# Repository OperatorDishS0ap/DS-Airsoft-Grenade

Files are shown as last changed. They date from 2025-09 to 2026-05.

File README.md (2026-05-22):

# DS-Airsoft-Grenade
## Current Release: [V5](/V5)
This project is a reusable, timed or impact-activated airsoft simulation grenade designed to operate with .209 primers, 8-shot ring caps, or adult/thunder/super snaps. The device is engineered with a strong emphasis on reliability, repeatability, and user safety. It is a zero-fragmentation system intended solely to produce an audible report, with no shrapnel or expelled components during operation. All exhaust gases and particulate byproducts are redirected and dispersed internally before exiting the device, significantly reducing localized pressure and minimizing external explosive forces.  
The design prioritizes consistent performance across a wide range of 3D printers and environmental conditions. Each component is optimized for printability, structural strength, and impact resistance while maintaining a compact form factor and minimal overall mass. A modular architecture allows both timed and impact fuse mechanisms to be easily interchanged between grenade bodies and compatible ammunition types, enabling flexibility in configuration, maintenance, and future expansion. This modularity, combined with durable construction, ensures the system remains adaptable, cost-effective, and dependable for repeated use in simulation environments.  

There may be inconsistencies with posted youtube videos and the current version or function. Please review the current [release](/V5)

Demo

[Ammo Comparison](https://youtube.com/shorts/NLlh_alYXCA?si=77kgigL3ZdaDLs44)

These are strictly for training and airsoft purposes. I do not assume any responsibility for your misuse or injury.  

# Changelog

All notable changes to this project will be documented below

## [5.0] - 2026-04-19  

###
- Created GitHub repository that will operate as the primary project resource
- All components have been redesigned for printability, reliability, and ease of use
- Added Multi-Shot Primer Body
- Changed from M5 SHCS Bolt to M4 FHCS and altered the guide to be bolted rather than press fit or glued
- Added aditional spring clearance for the use of uxcell springs
- Added aditional spring for increased spring strength
- New PCB design that implements a limit switch, battery protection, and LED indicator
- Time fuse is now activated with a pin
- Text size increased for multi-color printing
- Added constant force primer hole for better primer retention

## [4.2] – 2025-05-28

### Added
- New **timer design utilizing a custom PCB**
  - Supports **2S Li-Po** with a standard charger
  - No wires, hot glue, or crimping required
  - See the V4 release video or assembly video for details
- Motor removal access hole beneath the motor shaft
  - Allows easy motor removal using a metal rod
- Tool to assist with press-fitting the bolt guide
- **55-round snap body**
- V4 release video
- Updated assembly video

### Changed
- Enlarged **main bolt hole** and **bolt guide hole**
- External fuse body geometry updated for improved printability and durability
- Increased bolt guide height to further prevent slipping
- Completely redesigned spoon geometry
  - Printable in **TPU or PLA** using the same file
  - TPU remains recommended
  - Added groove to reduce sensitivity
- Inverted 8-cap orientation for easier use
- Increased snap hole sizes for easier removal
- Updated instructions and BOM
- Updated spring specification to **45 mm length or 8 coils**
  - See instructions for additional details

---

## [4.1] – 2025-02-19

### Fixed
- Corrected spelling on **8-cap** and **snap bodies**

### Added
- Long primer bodies (**DS38PL – PFL**)

---

## [4.0] – 2025-02-18

### Fixed
- Corrected BOM to list the proper **M2.5 × 3 mm set screw** for the timed fuse  
  - Previously listed **M2 set screw** may still work but can require adhesive or fail prematurely

### Added
- **DS40F no-text body**
- Initial **V4 release**

### Improvements
- Added support for **8-shot caps**, **adult snaps**, **super snaps**, and **thunder snaps**
- Reduced overall device size
- Added built-in guide on primer bodies for improved main bolt alignment
- Updated fuse dimensions for **40 mm half-thread bolt**
  - Smoother action
  - Smaller profile
- Converted bolt guide to a **press-fit design**
- Fuse now recesses into the body for improved strength
- Updated spoon dimensions
- Improved primer hole sizing



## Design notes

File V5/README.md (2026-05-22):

# PLEASE READ THE INSTRUCTIONS BELOW THOROUGHLY AND WATCH THE VIDEO LINKED BELOW BEFORE ASKING QUESTIONS

Assembly video can be found here: [Assembly Video](https://youtu.be/WyIGIuh09i8)

A video showing how to order the PCB can be found here: 

For further questions and resources join the [Discord](https://discord.gg/FcNPHcn7kz) server 

| Navigation |
| ------------------------ |
| [Printed Parts](#printed-parts) |
| [Impact Fuse BOM](#impact-fuse-bill-of-materials) |
| [Timed Fuse BOM](#impact-fuse-bill-of-materials) |
| [Impact Fuse Assembly](#impact-fuse-assembly) |
| [Timed Fuse Assembly](#timed-fuse-assembly) |
| [Body Assembly and Function](#body-assembly-and-function) |
| [Additional Material Info](#additional-material-info) |

# Printed Parts:
The tables below outline the printed parts necissary for each core component. You will need a fuse type and a body type. All fuses and bodies are interchangable. Links are to the corresponding file folders. **Materials are ordered from most to least recomended** If a material is not listed do not use it.
## Printed Parts for Impact Fuse:
| Part | QTY | Slicer Settings | Material | Support |
| --- | --- | --- | --- | --- |
| [Fuse](STL/ImpactFuse/FuseV5.STL) | 1 | ≤ 0.20mm layer height <br> Wall, top, and bottom thickness: ≥ 2 mm (5 walls for 0.4mm nozzle) <br> ≥ 35% Gyroid or Cubic Infill | TPU 72D <br> Nylon <br> PLA+ | No |
| [Bolt Guide](STL/ImpactFuse/BoltGuideV5.STL) | 1 | ≤ 0.16mm layer height <br> Wall, top, and bottom thickness: ≥ 2 mm (5 walls for 0.4mm nozzle) <br> 100% Infill | TPU 72D <br> Nylon | Yes |
| [Spring Plate](STL/ImpactFuse/SpringPlateV5.STL) | 1 | ≤ 0.16mm layer height <br> Wall, top, and bottom thickness: ≥ 2 mm (5 walls for 0.4mm nozzle) <br> 100% Infill | TPU 72D <br> Nylon | Yes |
| [Spoon](STL/ImpactFuse/Spoon) | 1 | ≤ 0.20mm layer height <br> Wall, top, and bottom thickness: ≥ 2 mm (5 walls for 0.4mm nozzle) <br> 100% Infill | TPU72D <br> TPU 95A | No |

## Printed Parts for Timed Fuse:
| Part | QTY | Slicer Settings | Material | Support |
| --- | --- | --- | --- | --- |
| [Fuse](STL/TimedFuse/PCBPinFuseV5.STL) | 1 | ≤ 0.20mm layer height <br> Wall, top, and bottom thickness: ≥ 2 mm (5 walls for 0.4mm nozzle) <br> ≥ 35% Gyroid or Cubic Infill | TPU 72D <br> Nylon <br> PLA+ | No |
| [Bolt Guide](STL/ImpactFuse/BoltGuideV5.STL) | 1 | ≤ 0.16mm layer height <br> Wall, top, and bottom thickness: ≥ 2 mm (5 walls for 0.4mm nozzle) <br> 100% Infill | TPU 72D <br> Nylon | Yes |
| [Spring Plate](STL/ImpactFuse/SpringPlateV5.STL) | 1 | ≤ 0.16mm layer height <br> Wall, top, and bottom thickness: ≥ 2 mm (5 walls for 0.4mm nozzle) <br> 100% Infill | TPU 72D <br> Nylon | Yes |
| [Cam](STL/TimedFuse/CamV5.STL) | 1 | ≤ 0.16mm layer height <br> Wall, top, and bottom thickness: ≥ 2 mm (5 walls for 0.4mm nozzle) <br> 100% Infill | ABS (CF/GF) <br> CF/GF Nylon <br> PLA+ | No |
| [Cap](STL/TimedFuse/CapV5.STL) | 1 | ≤ 0.20mm layer height <br> Wall, top, and bottom thickness: ≥ 2 mm (5 walls for 0.4mm nozzle) <br> ≥ 35% Gyroid or Cubic Infill | TPU 72D <br> Nylon <br> PLA+ | No |
| [Switch Lever](STL/TimedFuse/SwitchLeverV5.STL) | 1 | ≤ 0.20mm layer height <br> Wall, top, and bottom thickness: ≥ 2 mm (5 walls for 0.4mm nozzle) <br> ≥ 35% Gyroid or Cubic Infill | TPU 72D <br> Nylon <br> PLA+ | No |

## Printed Parts for Primer Body:
| Part | QTY | Slicer Settings | Material | Support |
| --- | --- | --- | --- | --- |
| [Body](STL/PrimerBody) | 1 | ≤ 0.20mm layer height <br> Wall, top, and bottom thickness: ≥ 2 mm (5 walls for 0.4mm nozzle) <br> ≥ 35% Gyroid or Cubic Infill | TPU 72D <br> Nylon | No |

## Printed Parts for Multi-Primer Body:
| Part | QTY | Slicer Settings | Material | Support |
| --- | --- | --- | --- | --- |
| [Body](STL/PrimerBody) | 1 | ≤ 0.20mm layer height <br> Wall, top, and bottom thickness: ≥ 2 mm (5 walls for 0.4mm nozzle) <br> ≥ 35% Gyroid or Cubic Infill | TPU 72D <br> Nylon | Yes |
| [Holder](STL/PrimerBody/Holder_X4.STL) | 1 | ≤ 0.16mm layer height <br> Wall, top, and bottom thickness: ≥ 2 mm (5 walls for 0.4mm nozzle) <br> ≥ 100% Infill | Nylon <br> PLA+ | No |

## Printed Parts for Snap Body
| Part | QTY | Slicer Settings | Material | Support |
| --- | --- | --- | --- | --- |
| [Body](STL/SnapBody) | 1 | ≤ 0.20mm layer height <br> Wall, top, and bottom thickness: ≥ 2 mm (5 walls for 0.4mm nozzle) <br> ≥ 35% Gyroid or Cubic Infill | TPU 72D <br> Nylon | Only for 55 Body |
| [Base](STL/SnapBody) | 1 | ≤ 0.20mm layer height <br> Wall, top, and bottom thickness: ≥ 2 mm (5 walls for 0.4mm nozzle) <br> ≥ 35% Gyroid or Cubic Infill | TPU 72D <br> TPU 95A <br> Nylon | No |

## Printed Parts for 8-Cap Body
| Part | QTY | Slicer Settings | Material | Support |
| --- | --- | --- | --- | --- |
| [Body](STL/CapBody) | 1 | ≤ 0.20mm layer height <br> Wall, top, and bottom thickness: ≥ 2 mm (5 walls for 0.4mm nozzle) <br> ≥ 35% Gyroid or Cubic Infill | TPU 72D <br> Nylon | No |
| [Retainer](STL/CapBody/CapRetainerV5.STL) | 1 | ≤ 0.16mm layer height <br> Wall, top, and bottom thickness: ≥ 2 mm (5 walls for 0.4mm nozzle) <br> ≥ 100% Infill | Nylon <br> PLA+ | No |

# Impact Fuse Bill of Materials:
### Please **VERIFY** that you are ordering the same component listed below. The links do not direct you to the exact size/specification you will need.

| Item | Quantity | Amazon | AliExpress | Notes |
| ---- | --- | --- | --- | --- |
| M4x45mm FHCS | 1 | [link](https://www.amazon.com/dp/B0D42CX288) | [link](https://www.aliexpress.us/item/3256807652024221.html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) | Main Bolt |
| M3x30mm Countersunk Self-Tapping Screw | 1 | [link](https://www.amazon.com/dp/B0D3ZW49WJ) | [link](https://www.aliexpress.us/item/3256807541973336.html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) | Spoon Bolt |
| 12mm OD x 40mm 1.2mm Diameter Spring | 1 | [link](https://www.amazon.com/dp/B076M2CBSX?ref_=ppx_hzsearch_conn_dt_b_fed_asin_title_2) | [link](https://www.aliexpress.us/item/2255800219014836.html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) | Primary Spring<br>See Comments Below |
| 8mm OD x 30mm 1mm Diameter Spring | 1 | [link]() | [link](https://www.aliexpress.us/item/3256805216136796.html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) | Secondary Spring<br>See Commenst Below |
| M4 Nut | 2 | [link](https://www.amazon.com/ZQZ-M4-0-7mm-Stainless-Hardware-Standard/dp/B0CQJJV8Q8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) | [link](https://www.aliexpress.us/item/2255800416538696.html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,scm-url:1007.40050.354490.0,pvid:712b6b0e-e0c3-48aa-a997-7cb9d9db5a1e,tpp_buckets:668%232846%238115%232000&pdp_ext_f=%7B%22order%22%3A%2211641%22%2C%22spu_best_type%22%3A%22price%22%2C%22eval%22%3A%221%22%2C%22sceneId%22%3A%2230050%22%2C%22fromPage%22%3A%22recommend%22%7D&pdp_npi=6%40dis%21USD%211.03%211.03%21%21%211.03%211.03%21%40210319b017731671023242410e8d3a%2110000003767007634%21rec%21US%212397384802%21XZ%211%210%21n_tag%3A-29919%3Bd%3A76bd9575%3Bm03_new_user%3A-29895&utparam-url=scene%3ApcDetailTopMoreOtherSeller%7Cquery_from%3A%7Cx_object_id%3A4000602853448%7C_p_origin_prod%3A) | For the Bolt and Spring Guide |
| M3x20mm Countersunk Self-Tapping Screw | 4 | [link](https://www.amazon.com/dp/B0D3ZW49WJ) | [link](https://www.aliexpress.us/item/3256807541973336.html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) | Fuse Reinforcement |
| 25mm/1" Keyring | 1 | [link](https://www.amazon.com/PAXCOO-Keyrings-Split-Keychain-Crafts/dp/B076Q9SSSQ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) | [link](https://www.aliexpress.us/item/3256804511691476.html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) | |
| M2.5x35mm Cotter Pin | 1 | [link]() | [link](https://www.aliexpress.us/item/3256804075588876.html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) | |
| M3 Brass Heat Insert 5mmODx4mmL | 1 | [link](https://www.amazon.com/dp/B0F43D2TTH) | [link](https://www.aliexpress.us/item/3256803396040989.html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) | Not necissary, only for increased durability |

Primary springs ordered from other locations may have differing coil counts. The recommended coil count is ~10-11, however, some experimentation may be needed. Both springs linked will work without modification. In the case the spring is unable to compress enough, either cut and stretch the spring, or purchase a shorter length and stretch to fit. If you find your springs too weak, increase in length. I recommend purchasing a few varying lengths or further discuss with others on the discord to find a good spring.  

The secondary spring is to add spring strength for the primer and 8-cap and is not necessary for the snap rounds.  

Springs will lose their strength over time and will need to be replaced. Avoid leaving springs compressed over long periods of time, as this will rapidly decrease their lifespan.

# Timed Fuse Bill of Materials:
### Please **VERIFY** that you are ordering the same component listed below. The links do not direct you to the exact size/specification you will need.

| Item | Quantity | Amazon | AliExpress | Notes |
| ---- | --- | --- | --- | --- |
| M4x45mm FHCS | 1 | [link](https://www.amazon.com/dp/B0D42CX288) | [link](https://www.aliexpress.us/item/3256807652024221.html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) | Main Bolt |
| 12mm OD x 40mm 1.2mm Diameter Spring | 1 | [link](https://www.amazon.com/dp/B076M2CBSX?ref_=ppx_hzsearch_conn_dt_b_fed_asin_title_2) | [link](https://www.aliexpress.us/item/2255800219014836.html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) | Primary Spring<br>See Comments Below |
| 8mm OD x 30mm 1mm Diameter Spring | 1 | [link]() | [link](https://www.aliexpress.us/item/3256805216136796.html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) | Secondary Spring<br>See Commenst Below |
| M4 Nut | 2 | [link](https://www.amazon.com/ZQZ-M4-0-7mm-Stainless-Hardware-Standard/dp/B0CQJJV8Q8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) | [link](https://www.aliexpress.us/item/2255800416538696.html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,scm-url:1007.40050.354490.0,pvid:712b6b0e-e0c3-48aa-a997-7cb9d9db5a1e,tpp_buckets:668%232846%238115%232000&pdp_ext_f=%7B%22order%22%3A%2211641%22%2C%22spu_best_type%22%3A%22price%22%2C%22eval%22%3A%221%22%2C%22sceneId%22%3A%2230050%22%2C%22fromPage%22%3A%22recommend%22%7D&pdp_npi=6%40dis%21USD%211.03%211.03%21%21%211.03%211.03%21%40210319b017731671023242410e8d3a%2110000003767007634%21rec%21US%212397384802%21XZ%211%210%21n_tag%3A-29919%3Bd%3A76bd9575%3Bm03_new_user%3A-29895&utparam-url=scene%3ApcDetailTopMoreOtherSeller%7Cquery_from%3A%7Cx_object_id%3A4000602853448%7C_p_origin_prod%3A) | For the Bolt and Spring Guide |
| M2.5x20mm Countersunk Self-Tapping Screw | 4 | [link]() | [link](https://www.aliexpress.us/item/3256807541973336.html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) | Fuse Cap Fastners and Reinforcement |
| 25mm/1" Keyring | 1 | [link](https://www.amazon.com/PAXCOO-Keyrings-Split-Keychain-Crafts/dp/B076Q9SSSQ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) | [link](https://www.aliexpress.us/item/3256804511691476.html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) | |
| M2.5x35mm Cotter Pin | 1 | [link]() | [link](https://www.aliexpress.us/item/3256804075588876.html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) | |
| Motor 12V 30RPM | 1 | [link](https://www.amazon.com/uxcell-Micro-Motor-10RPM-Reducer/dp/B01ES98QSG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)<br>[link](https://www.amazon.com/DC-Motor-1000-Miniature-3V-12V/dp/B08K9B1W5M/ref=sr_1_2?s=industrial&sr=1-2) | [link](https://www.alibaba.com/product-detail/Quiet-12mm-Ga12-n20-N10-N20_1600287077566.html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) | **DO NOT ORDER THE WRONG MOTOR**<br>See Comments Below To ensure you order the correct motor |
| 100mAh 3.7V Li-Po w/ JST PH2.0mm Connector | 2 | [link]() | [link]() | See the Image Below for Battery Space Measurements |
| Male JST PH2.00mm 3P Connector | 1 | [link](https://www.amazon.com/CQRobot-Pieces-Connector-Housing-Adapter/dp/B09YY18S91/ref=sr_1_6?sr=8-6) | [link](https://www.aliexpress.us/item/3256804853397341.html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) | Charger Cable |
| Male JST XH2.54mm 3P Connector | 1 | [link](https://www.amazon.com/Antrader-Silicone-Battery-Extension-Connector/dp/B07TTR598D/ref=sr_1_9?sr=8-9) | [link](https://www.aliexpress.us/item/3256806041022852.html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) | This is for charging the 2S Li-Po in the fuse. I recommend purchasing a 2S Li-Po balance lead and crimping the JST PH2.0mm connector to the end. Otherwise, you can crimp the connectors on both ends. |
| M2.5x3mm Set Screw | 1 | [link](https://www.amazon.com/100pcs-Stainless-Socket-Screws-Metric/dp/B01MTM26H0/ref=sr_1_9?sr=8-9) | [link](https://www.aliexpress.us/item/2255800895118752.html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) | Timer Cam |
| Limit Switch SPDT | 1 | [link]() | [link](https://www.aliexpress.us/item/3256805410237576.html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) | Ensure you get a side mount switch <br> The metal switch lever will be removed |
| PCB | 1 | | | PCB [Files](PCB) are above<br>A [video]() showing how to order the board is linked above |
| Female JST PH2.0mm 2P Vertical Header | 2 | [link](https://www.amazon.com/CQRobot-Pieces-Connector-Housing-Adapter/dp/B09DP9FZTX/ref=sr_1_6?s=industrial&sr=1-6) | [link](https://www.aliexpress.us/item/3256806894018733.html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) | Battery PCB Header |
| Female JST PH2.0mm 3P Horizontal Header | 1 | [link](https://www.amazon.com/CQRobot-Pieces-Connector-Housing-Adapter/dp/B09YY18S91/ref=sr_1_6?sr=8-6) | [link](https://www.aliexpress.us/item/3256804853397341.html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) | Battery PCB Charge Port Header |

**DO NOT ORDER THE WRONG MOTOR.** It is Very important that you purchase a 12V-30rpm/6V-15rpm motor. The gearbox is ~12.5mm vs the standard 9mm. The gearbox has ~1:1000 ratio. Please be careful to order the correct motor, others will not work. I recommend ordering from the Alibaba link, please specify the **“KGM12-N20-C. 12V 1/1000 reduction ratio”** when ordering.  

Primary springs ordered from other locations may have differing coil counts. The recommended coil count is ~10-11, however, some experimentation may be needed. Both springs linked will work without modification. In the case the spring is unable to compress enough, either cut and stretch the spring, or purchase a shorter length and stretch to fit. If you find your springs too weak, increase in length. I recommend purchasing a few varying lengths or further discuss with others on the discord to find a good spring.  

The secondary spring is to add spring strength for the primer and 8-cap and is not necessary for the snap rounds.  

Springs will lose their strength over time and will need to be replaced. Avoid leaving springs compressed over long periods of time, as this will rapidly decrease their lifespan.

Battery compartment dimensions are below in millimeters. You will have to explore options for batteries since listings change per country. Verify that it has a JST PH 2.0mm connector or crimp your own.

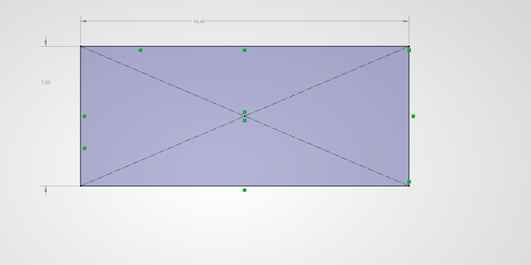
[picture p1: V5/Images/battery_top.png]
Top Battery Space

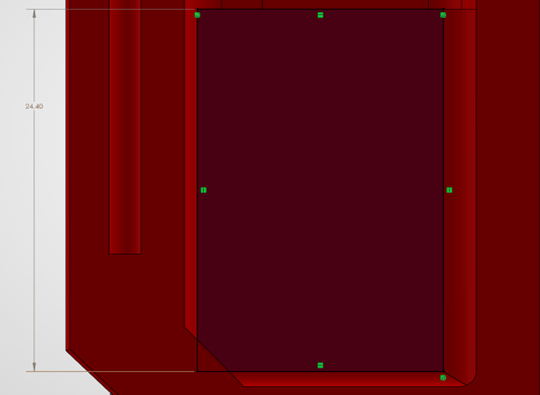
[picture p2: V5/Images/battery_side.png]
Side Battery Space


# Multi-Primer Bill of Materials:
### Please **VERIFY** that you are ordering the same component listed below. The links do not direct you to the exact size/specification you will need.

| Item | Quantity | Amazon | AliExpress |
| ---- | --- | --- | --- |
| 3mm OD x 20mm 0.4mm Spring | 1 | [link](https://www.amazon.com/uxcell-Compression-Spring-Stainless-Length/dp/B0C33CBS5Y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) | [link](https://www.aliexpress.us/item/3256805216186612.html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) |
| 3.175mm / 1/8" Ball Bearing | 1 | [link](https://www.amazon.com/uxcell-8-inch-Bearing-Stainless-Precision/dp/B07YFXDZQS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) | [link](https://www.aliexpress.us/item/3256805018276561.html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) |
| M3x20mm BHCS | 1 | [link](https://www.amazon.com/iexcell-Thread-Socket-Button-Screws/dp/B0CP49NWYB/ref=sr_1_3?sr=8-3) | [link](https://www.aliexpress.us/item/2251832780910689.html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,scm-url:1007.40050.354490.0,pvid:030ae71f-b872-4ad4-aca8-7f85ee968ba4,tpp_buckets:668%232846%238115%232000&pdp_ext_f=%7B%22order%22%3A%2214068%22%2C%22eval%22%3A%221%22%2C%22sceneId%22%3A%2230050%22%2C%22fromPage%22%3A%22recommend%22%7D&pdp_npi=6%40dis%21USD%211.11%211.11%21%21%211.11%211.11%21%4021033d1217731699782175040ecb48%2112000015921238834%21rec%21US%212397384802%21X%211%210%21n_tag%3A-29919%3Bd%3A76bd9575%3Bm03_new_user%3A-29895&utparam-url=scene%3ApcDetailTopMoreOtherSeller%7Cquery_from%3A%7Cx_object_id%3A32967225441%7C_p_origin_prod%3A) |
| M4x5mm Set Screw | 1 | [link](https://www.amazon.com/ZDingTech-110pcs-Screws-Stainless-Hexagon/dp/B0CF299SDT/ref=sr_1_3?sr=8-3) | [link](https://www.aliexpress.us/item/2255800895118752.html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) |

# Impact Fuse Assembly:
#### It is recommended to watch the assembly video as well

1. To start, for the primer version only, grind the end of the fuse screw (m4x45mm) to a bevel as shown in the image below. Do not sharpen the tip this will puncture the primer. A point around 3mm in diameter is ideal.  
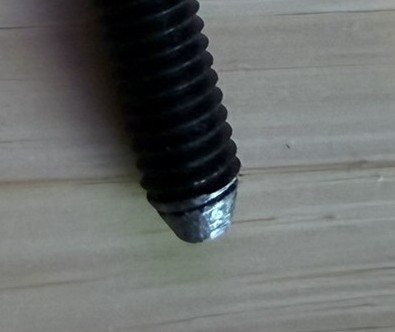
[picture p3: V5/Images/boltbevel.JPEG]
Beveled Bolt


2. Remove any support materail and press an m4 nut into the bolt guide and the spring plate. Screw the m4x45mm screw into to bot guide.   
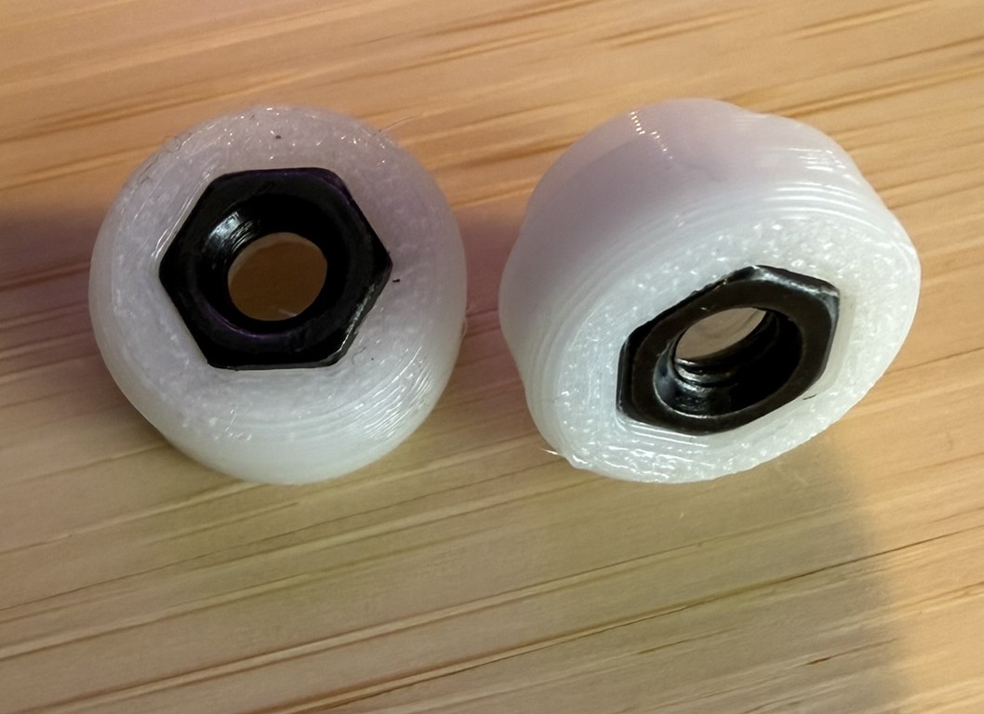
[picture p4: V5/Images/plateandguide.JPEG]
bolt guide and spring plate
  
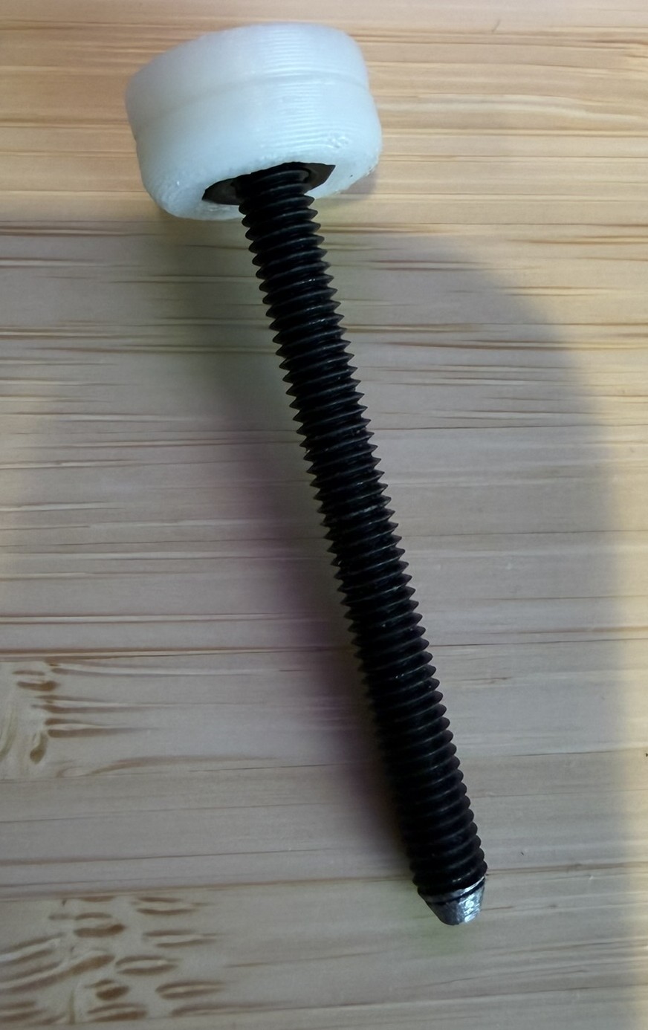
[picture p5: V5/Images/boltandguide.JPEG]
bolt guide and bolt
  

3. Secure the main screw, primary, and secondary springs in the fuse with the spring retainer. For use with primers ensure that the bolt sticks out ~2mm past the spring retainer as seen in the photo below.  
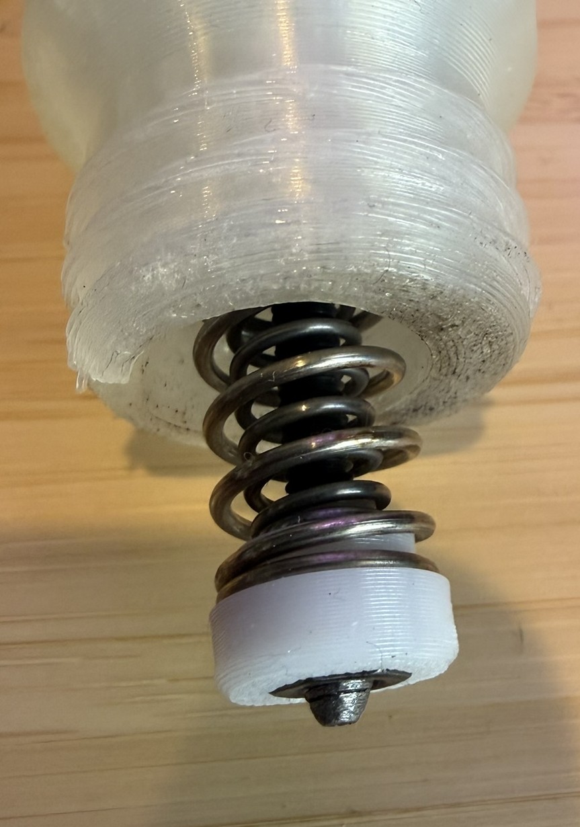
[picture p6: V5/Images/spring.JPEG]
Add Springs


4. Insert four m3x20mm self-tapping screws for reinforcement.  
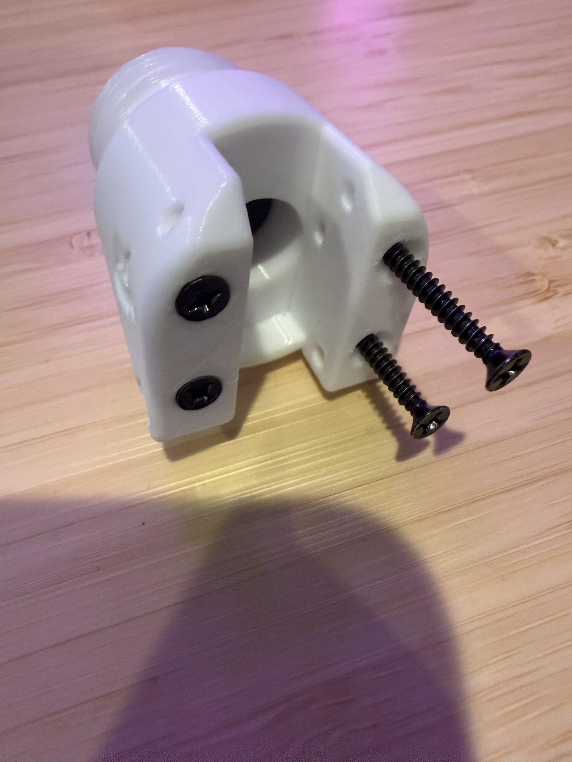
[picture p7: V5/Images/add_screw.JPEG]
Add m3 screws


5. The spoon can now be secured by the m3x30mm screw. If necessary, the width of the spoon can be increased or decreased in your slicer by modifying its z scale. The fuse performs best when the spoon moves freely without resistance. The tab on the inside face of the spoon can also be trimmed or sanded for increased sensitivity.  
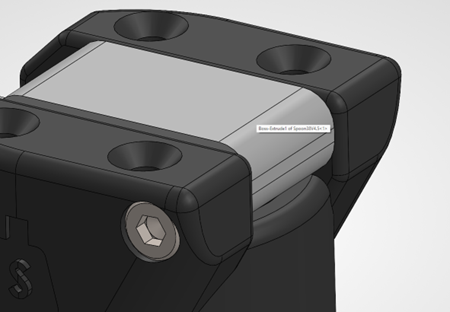
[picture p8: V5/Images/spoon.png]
Spoon

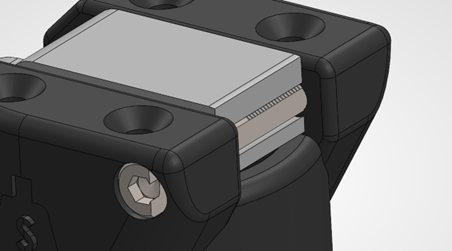
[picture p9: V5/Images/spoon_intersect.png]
Intersected Spoon

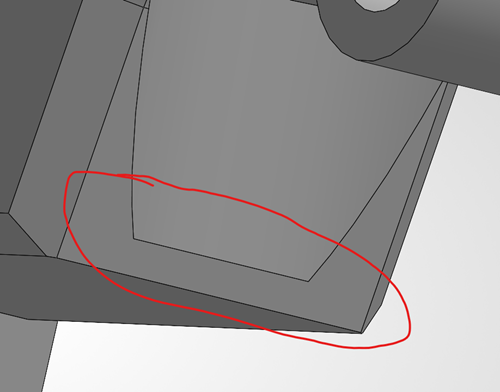
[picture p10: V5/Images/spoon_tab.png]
Spoon Tab
  
Trim or sand the Tab for increased sensitivity  
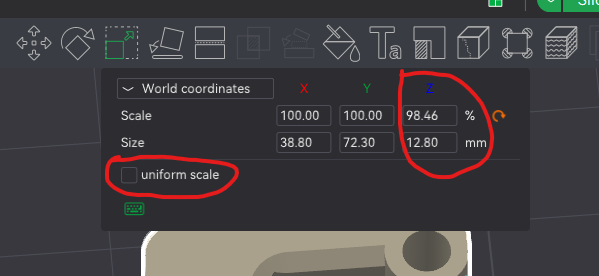
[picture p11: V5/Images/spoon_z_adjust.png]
Spoon Sicer Adjustment
  
Bambu Studio Spoon Width Adjustment  

6.	In order to prime the fuse, the m4 screw needs to be pushed up and towards the rear as shown in the image below. The spoon will then be lowered in order to hold the screw from dropping.  
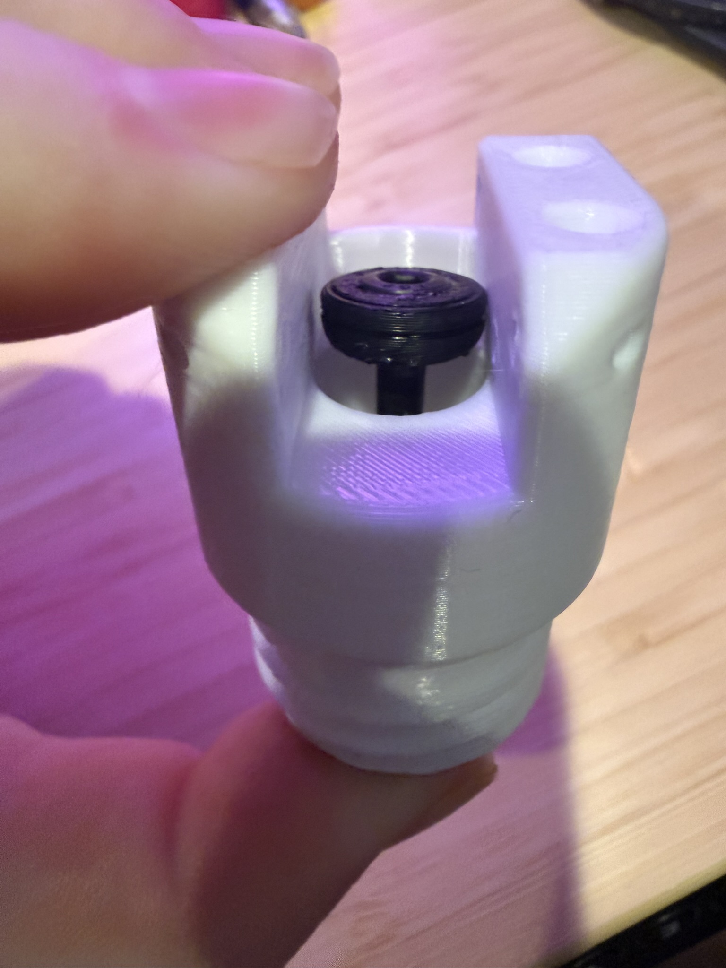
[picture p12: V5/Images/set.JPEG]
Set the Fuse
  
Priming animation

The screw is not supposed to catch on the top and should free fall unless something is blocking it. The spoon is blocking the screw from falling into the hole. The fuse will trigger when the spoon moves away from the bolt guide. This can be accomplished with a hard impact or simply moving the spoon. Again, adjusting the tab on the spoon by trimming or sanding adjusts the force required for the spoon to move out of the way. Be careful to not make it too sensitive otherwise the force used to throw is enough to trigger the fuse.  

Throw the device underhand. If thrown overhand, hold it in the position shown below. Throwing in this orientation reduces the force on the fuse mechanism to avoid triggering in flight or upon release.  
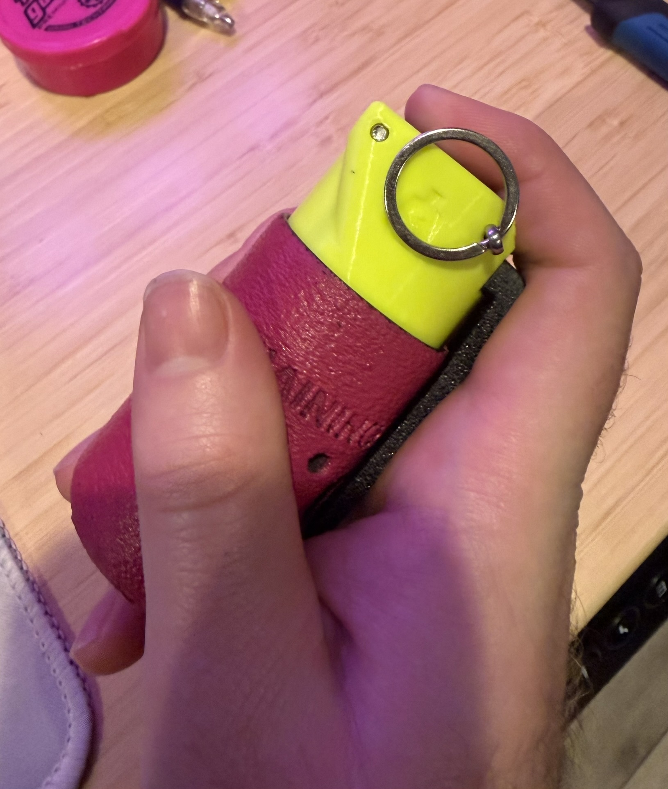
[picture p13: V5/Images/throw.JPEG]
How to throw overhand


# Timed Fuse Assembly:
### It is recommended to watch the assembly video as well

1. To start, for the primer version only, grind the end of the fuse screw (m4x45mm) to a bevel as shown in the image below. Do not sharpen the tip this will puncture the primer. A point around 3mm in diameter is ideal.  
Beveled Bolt

2. Remove any support materail and press an m4 nut into the bolt guide and the spring plate. Screw the m4x45mm screw into to bot guide.   
bolt guide and spring plate  
bolt guide and bolt  

3. Secure the main screw, primary, and secondary springs in the fuse with the spring retainer. For use with primers ensure that the bolt sticks out ~2mm past the spring retainer as seen in the photo below.  
Add Springs

4. Remove the built in support from the fuse body.  
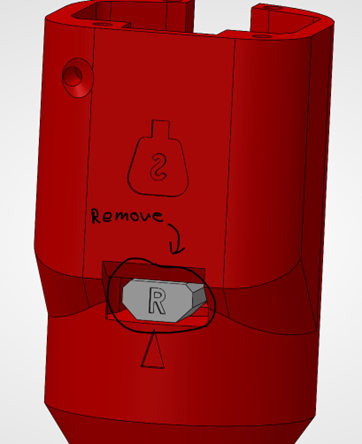
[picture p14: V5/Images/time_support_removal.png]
Remove Support from the timer
  

5.	Solder the Headers/Connectors and Motor to the PCB as Imaged below. Remove the metal lever from the switch. Trim the extra pin length after soldering. **GOING FORWARD DO NOT PRESS THE BUTTON UNTIL INSTRUCTED TO DO SO**  
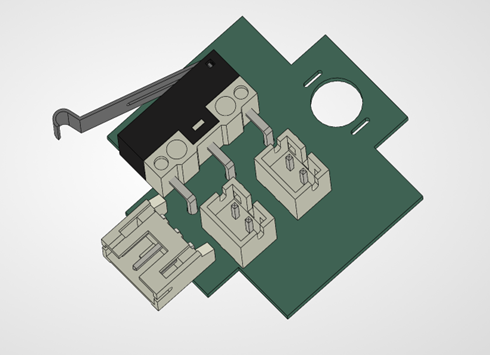
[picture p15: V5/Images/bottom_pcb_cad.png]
Bottom PCB CAD

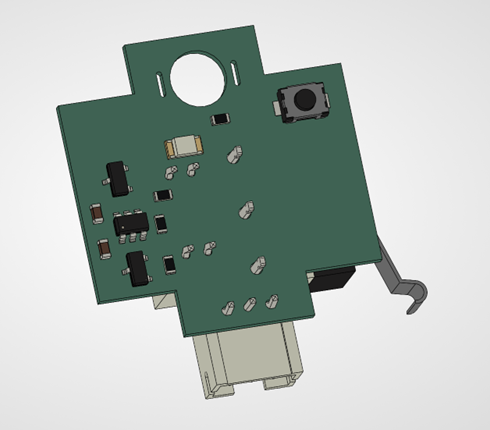
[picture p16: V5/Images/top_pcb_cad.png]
Top PCB CAD
  
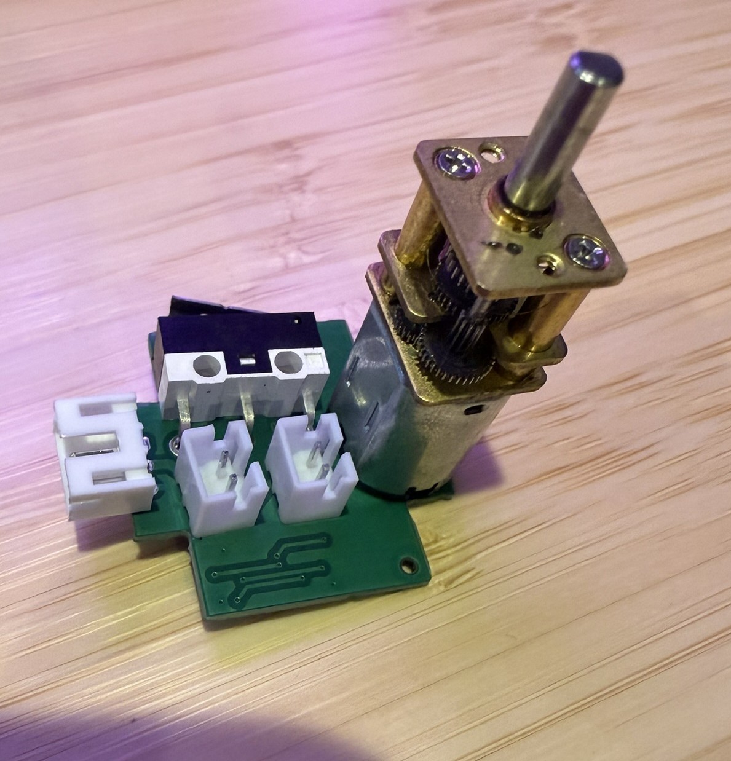
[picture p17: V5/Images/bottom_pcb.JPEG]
Bottom PCB
  
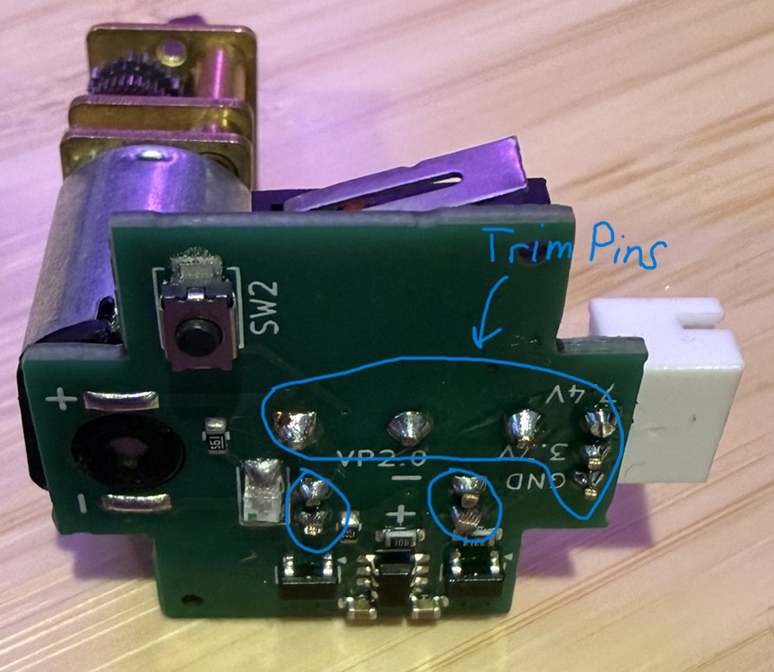
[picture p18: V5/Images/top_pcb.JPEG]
Top PCB
   
Trim the Excess Pin Lenght from the Headers and Switch to avoid touching the cap  

6.	Plug the Batteries in the order labeled. **VERIFY THE POLARITY IS CORRECT.** It is critical that you do this correctly or risk harming the board. When disassembling, unplug the batteries in the reverse order (#2 first then #1). AGAIN, **DON’T PRESS THE BUTTON.**
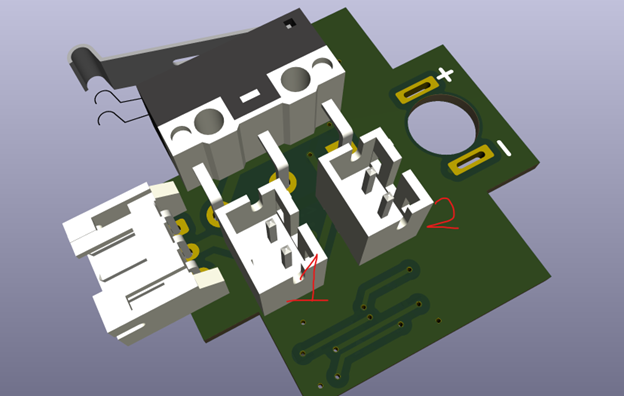
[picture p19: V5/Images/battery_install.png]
Battery Install Order


7.	Add the screw to the cam. Thread the set screw all the way through to remove additional material. Leave screw out until later. Verify the cam fits the motor shaft.  
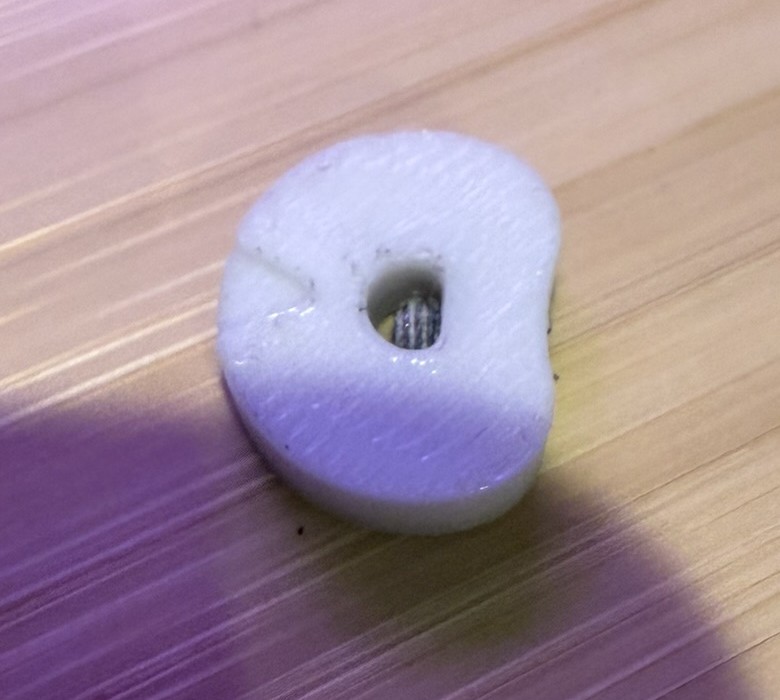
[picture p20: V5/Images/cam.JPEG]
Cam


8.	Insert the PCB assembly and cam into the fuse. You can use a pin to hold the cam in the center like imaged below. Ensure the notch on the cam is facing down. Rotate the cam to match the motor shaft to insert fully. Ensure the battery wires are orientated as shown in the image and the wires are not being pinched. There is a small cutout for the wires under the switch.
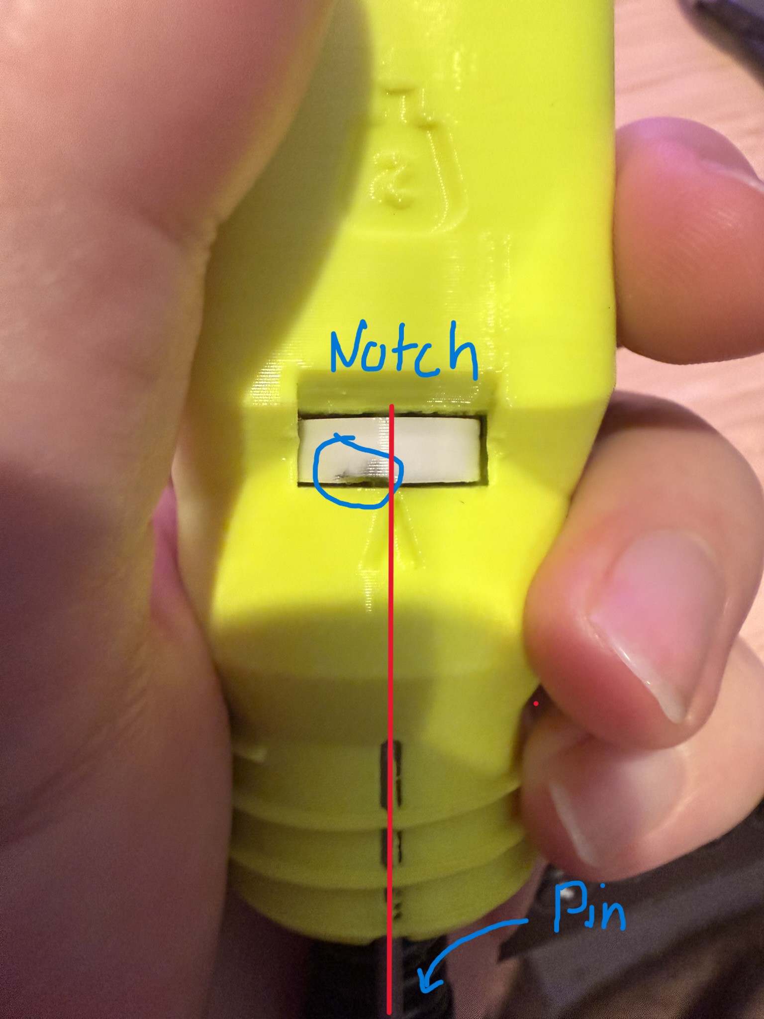
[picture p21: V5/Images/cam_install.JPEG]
Cam Install
  
Note the Pin inserted from the bottom holding the cam in place and the cam notch is facing down

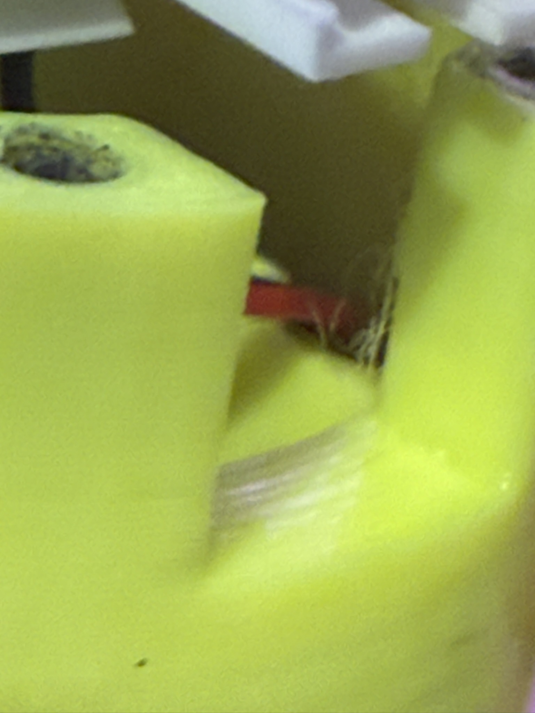
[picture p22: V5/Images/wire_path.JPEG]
Wire Channel Left
  
Make sure the wires for the battery on the left are exiting through the cutout to prevent them from getting pinched by the switch  

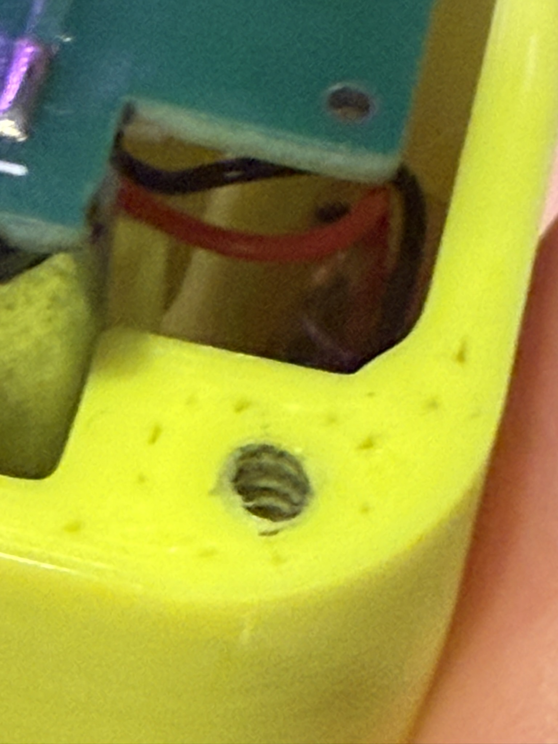
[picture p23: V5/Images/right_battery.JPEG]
Right BAttery
  
Right Battery  

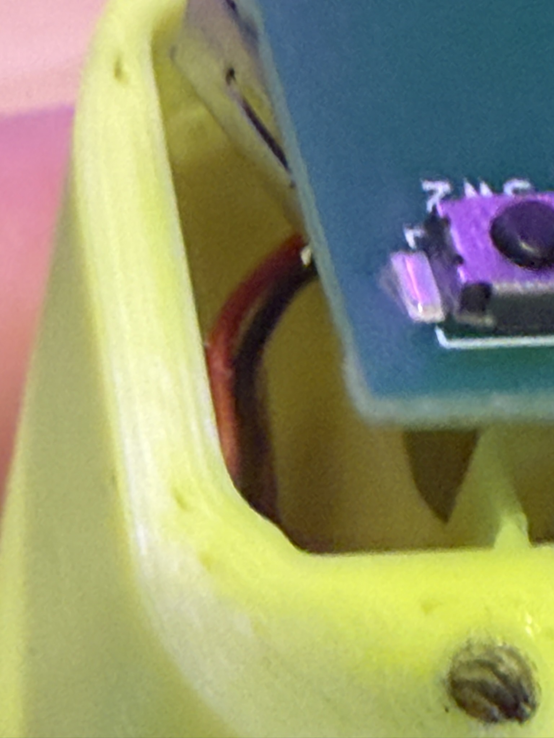
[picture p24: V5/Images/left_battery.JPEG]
Left Battery
  
Left Battery  

9. Now Fasten the printed switch lever and cap using 4 m2.5X25mm screws.  
Fuse no switch  
Fuse switch  
Fuse Cap  

9.	Now press the button to reset the battery protection circuit. The motor will now turn continuously if there is nothing pressing onto the switch. Stop the motor by inserting a pin to press the switch. If the board does not power, ensure that your batteries are charged and they were installed in the correct order and polarity. Fasten the cap once you confirm the motor is turning. Stop the motor when the cam is located with the set screw facing out. Install the set screw. Using superglue on the set screw is encouraged.

10.	Finally, to use the timed fuse stop the cam when the notch lines up with the arrow on the fuse body. Push the main bolt up and to the rear like you would the impact fuse. While holding it up and to the rear, advance the cam a small amount to catch or limit the bolt from falling. Now when the pin is pulled the cam will rotate and the bolt will eventually fall. The timing can easily be reduced by advancing the cam further when setting. Re-insert the pin to stop the mechanism upon retrieval.
Alighn the Cam Notch  
Align the Cam Notch with the Arrow to Allow the Bolt to Move Up  

Timer Set  
Note the Bolt is all the way up and the cam has been advanced preventing it from falling  

Timer Fuse Function  

11.	To charge the fuse use a 2S Li-Po charger and the charging port on the side of the fuse. Below is a picture of a charging cable with labeled pins. Ensure that your wires are correct. There is a pinout on the PCB for further confirmation. If your charger requires you to plug in the main connector in addition to the balance lead, add two additional wires and a connector of your choice (Deans, jst, banana, etc.) like shown in green.
Charge Cable

### Notes:
- The fuse will continuously spin until the switch is depressed with the pin.
- I measured over 1h 30min runtime. This is far more than I’ve ever needed and will allow you many uses given you retrieve it after throwing in a reasonable time.
- In case the batteries run out, the protection circuit will stop the batteries from being discharged further. Re-charge the batteries and reset the protection circuit with the button on top.
- If the motor spins freely in the cam, the D shaped hole becomes rounded, use glue when inserting the set screw. If the problem still occurs print the cam using a more rigid material such as a fiber reinforced material.  

# Body Assembly and Function:

### Primer Body:
The Primer will be loaded in the location outlined in the photo below. It can be pushed out after use from the bottom of the body. If the hole is not the right size, I suggest using x-y hole compensation in your slicer.  
Primer Body  
Slicer Hole Compensation  
Bambu Studio X-Y Hole Compensation  

### Multi-Primer Body
Insert the Holder into the body.  
Holder  

Screw the holder Down. Do not tighten all the way. The Holder needs to be able to rotate.  
Holder Screw  

Insert the ball bearing followed by the spring into the hole on the side. Insert the set screw to confine the spring and ball. Tighten until it becomed difficult to rotate the holder from position to position.  
Ball Bearing  

### Cap Body:
The 8-shot cap can be placed over the retainer then placed in the body as seen below  
8 Cap Body  

### Snap Body:
Remove the built in support  
Remove Support for Snap Body  

Insert the snaps as shown  
Insert Snaps  

The bottom can then be screwed on to secure the snaps from falling out  
Snap Bottom  

# Additional Material Info:
Begin printing with TPU 72D, Nylon, PLA+ were applicable before experimenting with alternative materials. TPU 72D is a supperior material for impact resistance. Also, TPU is a safer body material. When a failure occurs TPU will tear rather than shatter like PLA+, Nylon, etc. When changing materials, modify only one variable at a time to accurately identify the source of any issues.  

## TPU 72D or Harder
Through testing, [CC3D 72D TPU](https://www.amazon.com/CC3D-Hardness-Transparent-Toughness-Comparable/dp/B0CFY1S38G/ref=sr_1_4?sr=8-4) has proven to be an excellent material choice. It offers an exceptional balance of rigidity, impact absorption, and layer adhesion. When printed correctly, parts made from this material are extremely durable. 

### Recomended Slicer Setting for CC3D 72D TPU
To achieve reliable results, use the following settings:
- Dry the filament thoroughly<br>Like nylon and TPU, this material absorbs moisture aggressively.
- Outer wall speed: ≤ 40 mm/s
- Inner wall speed: ≤ 60 mm/s
- Seam position: Nearest

I also recomend annealing parts in boiling water for ~1 hour. This will stabalize its elastic carracteristics over a broader range of temperatures. It will also aid in layer adhesion.

## Nylon (Non-Fiber Reinforced)
Non-fiber-reinforced nylon is a significantly better alternative to PLA+. Use only raw nylon formulations, such as [Overture Easy Nylon]( https://www.amazon.com/OVERTURE-Filament-Consumables-Polyamide-Dimensional/dp/B087R3M9Z2/ref=sr_1_1_pp?sr=8-1), which offer superior impact absorption and stronger layer adhesion. For optimal performance, annealing printed nylon parts is strongly recommended. 

## Fiber-Reinforced Materials (Not Recomended)
Avoid fiber-reinforced filaments such as carbon fiber and glass fiber blends. While these materials increase rigidity, they also make parts significantly more brittle. Under impact, this high rigidity can cause parts to shatter rather than absorb energy. Additionally, fiber additives reduce layer adhesion, which is critical to the safe and reliable operation of these devices. The timer cam is the only component where increased rigidity is beneficial, as it helps prevent the motor shaft hole from rounding out. For this specific part only, a more rigid or fiber-reinforced material may be used.

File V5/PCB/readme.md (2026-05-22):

# How to Order PCB  

1. Navigate to [JLCPCB](jlcpcb.com). Create an account and navigate to the Standard PCB/PCBA order menu.
2. Upload the [PCBV2.0.0.zip](PCBV2.0.0.zip). It is the gerber file.
3. Select your board quantity. Change PCB thickness to 1.0mm. Change the PCB color if you want. Select PCB Assembly. Leave all other specifications as they are.
4. Click Next and verrify the board is displayed. Click Next again.
5. Upload the [BOM](bom.csv) File. Upload the [CPL](positions.csv) File (positions). Then Click process BOM & CPL.
6. All parts should prepopulate. Ignore the error for an unmatched component J4 Motor. Click Next and select do not place for the motor component error.
7. Components are already properly placed so just click next.
8. Select a product description. I typically do Sensor\Controller\Precision Intrument, Battery - HS Code 853890. Then save to cart.
9. At this point you can procede to checkout
10. Don't forget to order the switch and connectors for the board listed in the BOM. These parts will need to be hand soldered.

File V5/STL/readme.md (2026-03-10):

Files are in labeled folders above. A list of necessary parts can be found [here](../README.md/#printed-parts)

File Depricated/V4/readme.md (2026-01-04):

# Depricated: Please View the Current Release Indicated [Here](../../)

V4 [Video](https://youtu.be/80pCEygZt8I)

Impact [Demo](https://youtube.com/shorts/6eM99irWegU?feature=share)

Timed Version [Demo](https://youtube.com/shorts/Hy5njhvKSrs?si=KscytKjcjW3jRwIt)

These are strictly for training and airsoft purposes. I do not assume any responsibility for your misuse or injury.

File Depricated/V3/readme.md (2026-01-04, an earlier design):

# Depricated: Please View the Current Release Indicated [Here](../../)

V3 [Video](https://youtu.be/1QZiijmwaFE?si=J8ztw9y8YyzhfrAc)

For those still using V3, I would encourage you to use the [guide mod](https://cults3d.com/en/3d-model/various/guide-for-dishsoap-airsoft-grenade) created by teddebeezy.

These are strictly for training and airsoft purposes. I do not assume any responsibility for your misuse or injury.

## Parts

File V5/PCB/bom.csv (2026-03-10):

Designator | Footprint | Quantity | Value | LCSC Part #
C1, C2 | 0603 | 2 | 0.1u | C14663
D1 | 805 | 1 | LED | C2297
J1 | JST_PH_B2B-PH-K_1x02_P2.00mm_Vertical | 1 | Battery 1
J2 | JST_PH_B2B-PH-K_1x02_P2.00mm_Vertical | 1 | Battery 2
J3 | JST_PH_S3B-PH-K_1x03_P2.00mm_Horizontal | 1 | Charger
J4 | N20 | 1 | Motor
Q1, Q2 | SOT-23 | 2 | AO3400A | C20917
R1, R2 | 0603 | 2 | 330 | C23138
R3 | 0603 | 1 | 2k | C22975
R4 | 0603 | 1 | 560 | C23204
SW1 | SW_XKB_DM1-16UD-1 | 1 | SW_SPDT
SW2 | SW_SPST_TS-1088-xR020 | 1 | SW_Push | C720477
U1 | SOT-23-6 | 1 | HY2120-CB | C116509

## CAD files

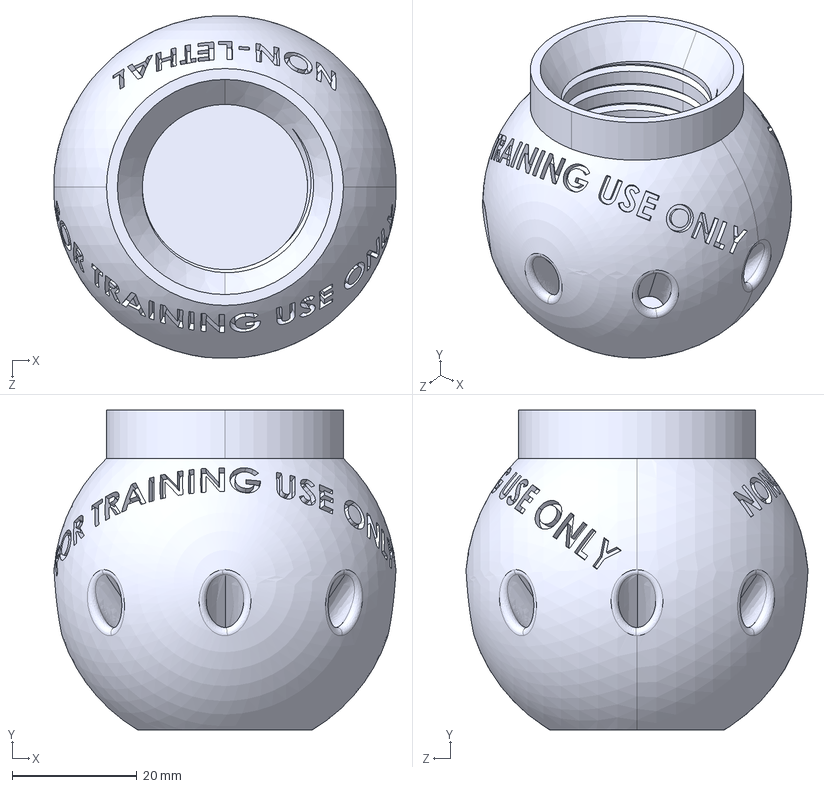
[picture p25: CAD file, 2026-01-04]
Depricated/V4/8CapBodies/DS558.STEP
54.9 x 51.3 x 54.9 mm

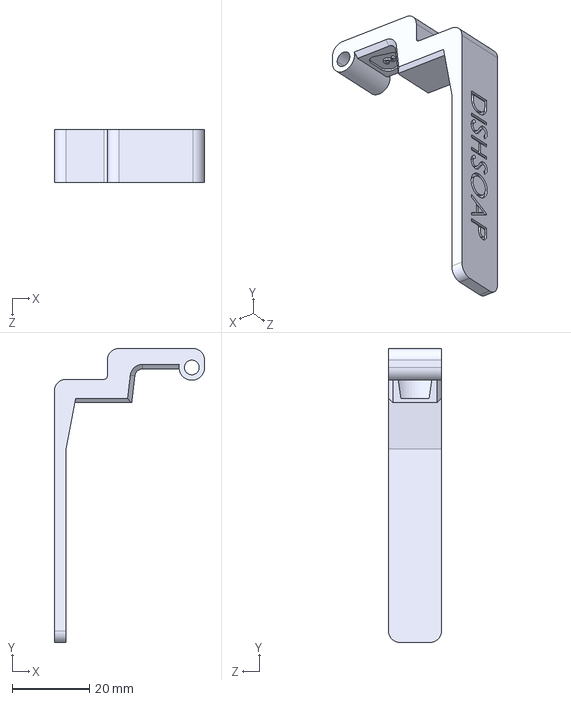
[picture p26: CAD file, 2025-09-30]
Depricated/V4/ImpactFuse/Spoons/Spoon38S_8.STEP
38.8 x 76.0 x 13.7 mm

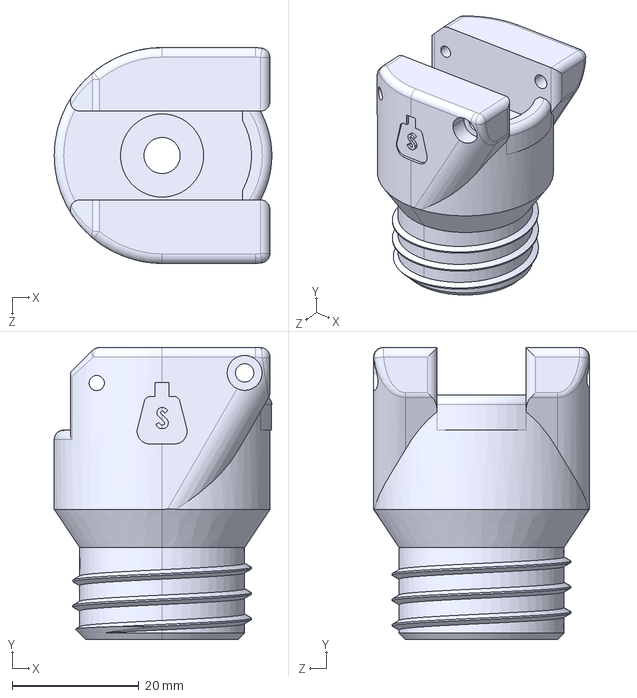
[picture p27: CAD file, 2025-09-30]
Depricated/V4/ImpactFuse/V4Fuse_HeatInsert.STEP
34.3 x 46.0 x 34.0 mm

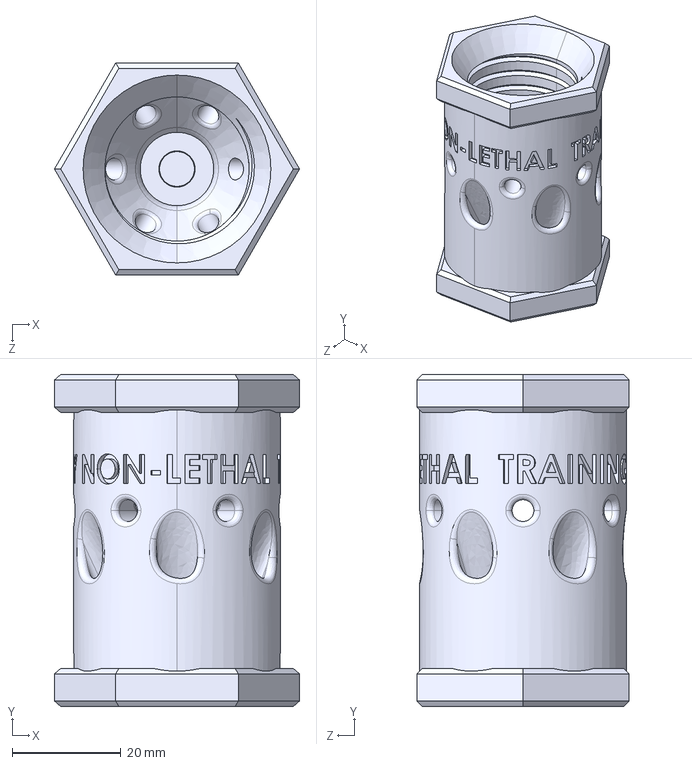
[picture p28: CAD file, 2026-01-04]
Depricated/V4/PrimerBodies/DS38PF.STEP
45.0 x 61.0 x 39.0 mm

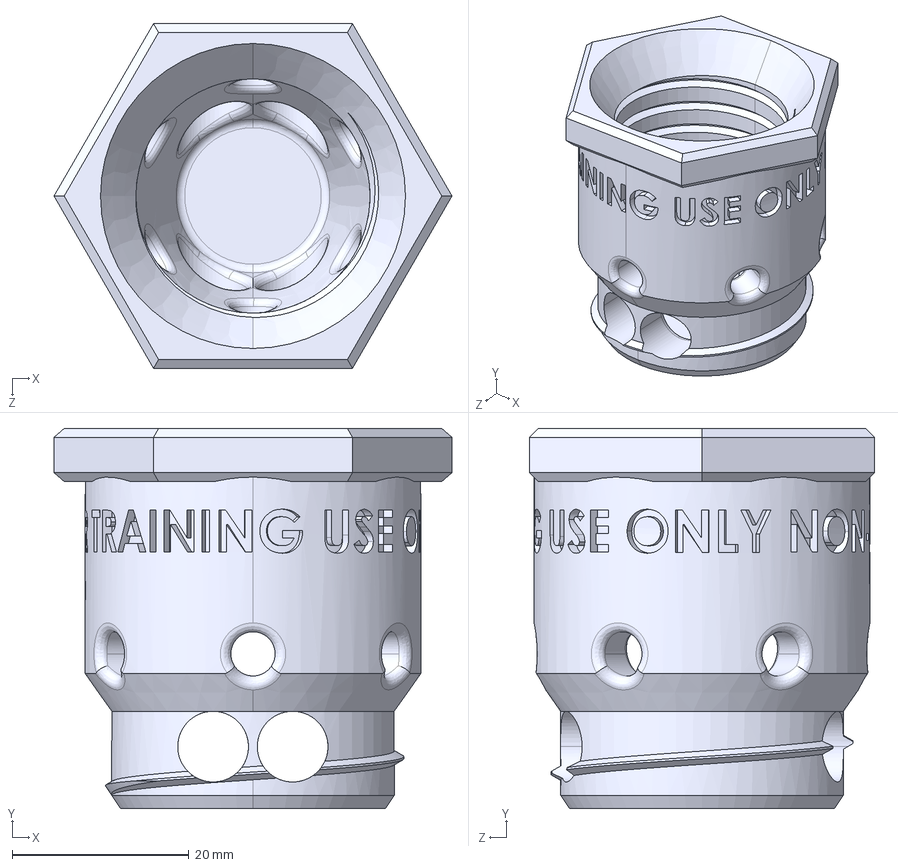
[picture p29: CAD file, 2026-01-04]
Depricated/V4/SnapBodies/DS38SFTop.STEP
45.0 x 43.0 x 39.0 mm

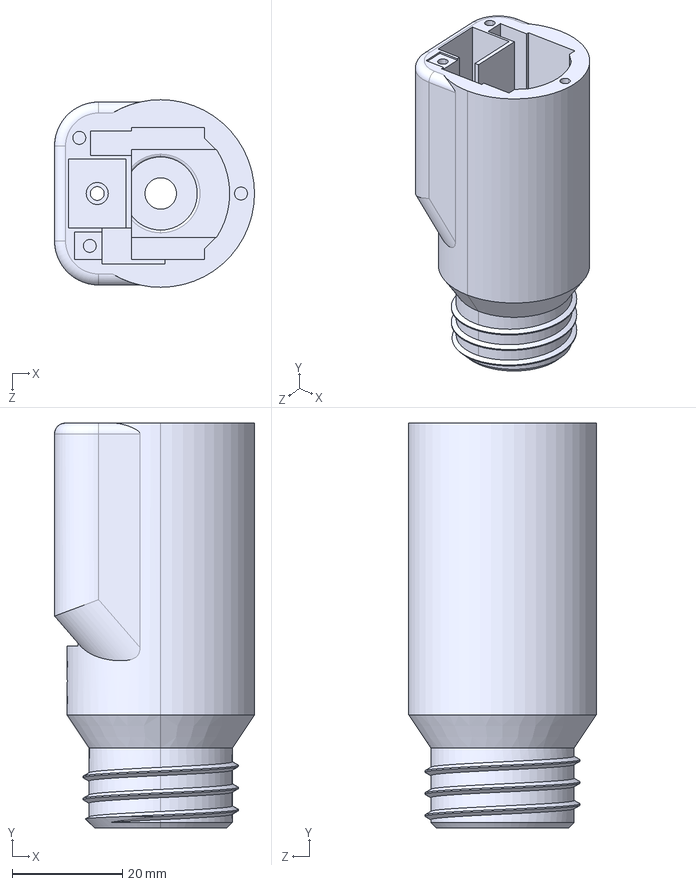
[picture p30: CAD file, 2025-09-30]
Depricated/V4/TimedFuse/BasicTimer/TimerBody.STEP
36.3 x 73.4 x 34.0 mm

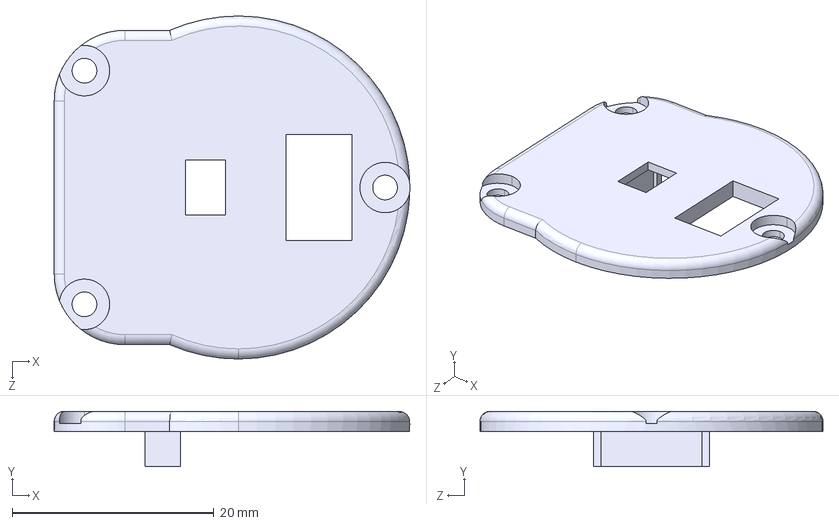
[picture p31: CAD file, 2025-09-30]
Depricated/V4/TimedFuse/PCBTimer/timerV4pcbcap.STEP
35.2 x 5.50 x 34.0 mm

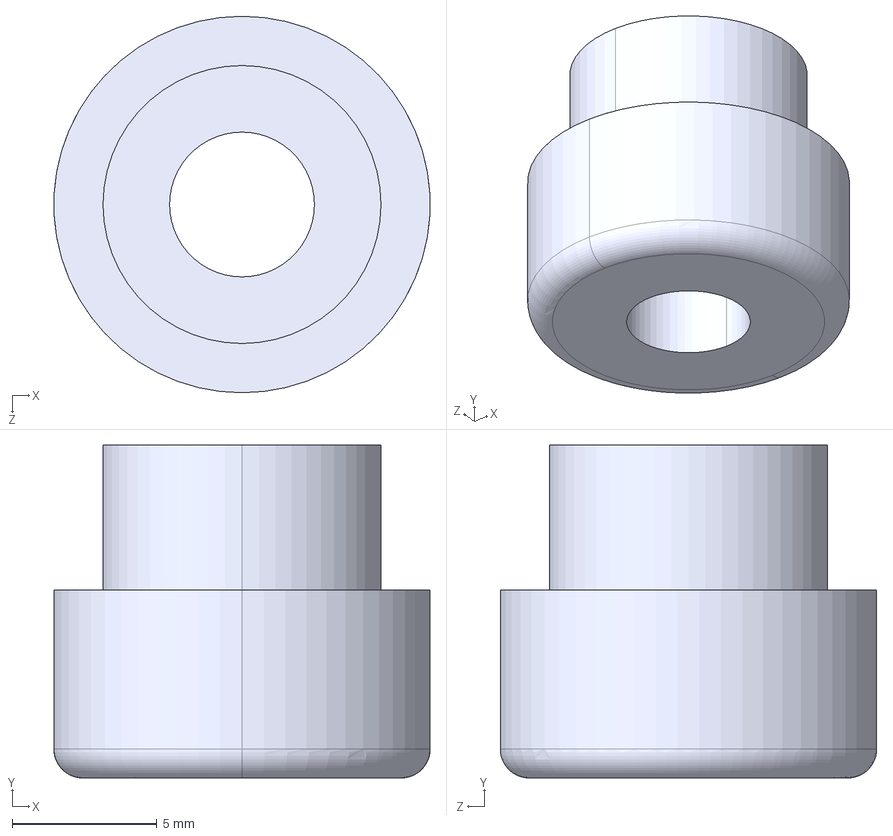
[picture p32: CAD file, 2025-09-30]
Depricated/V4/TimedFuse/SpringPlate.STEP
13.0 x 11.5 x 13.0 mm

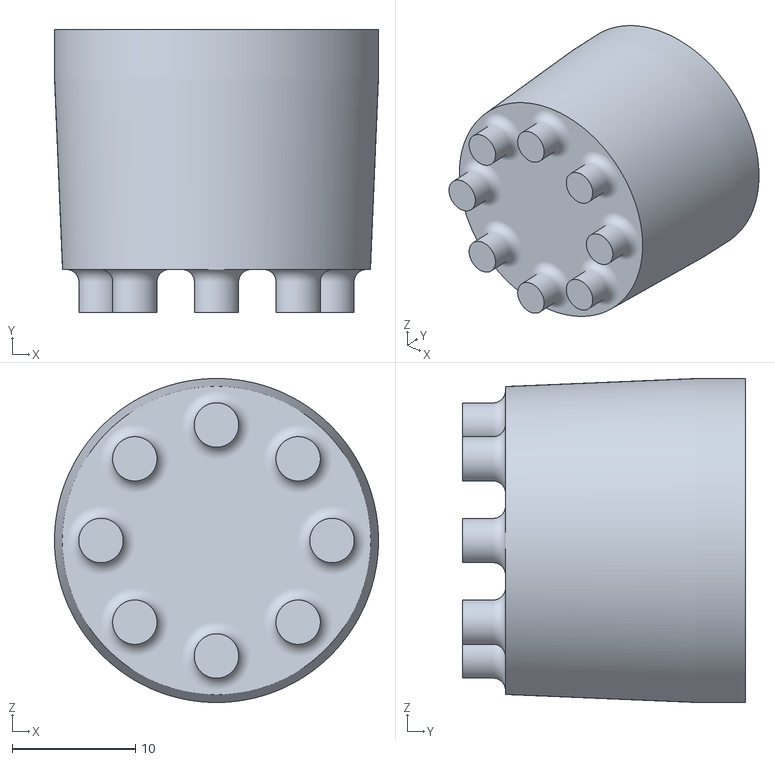
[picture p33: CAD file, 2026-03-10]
V5/STL/CapBody/CapRetainerV5.STL
26.3 x 23.0 x 26.3

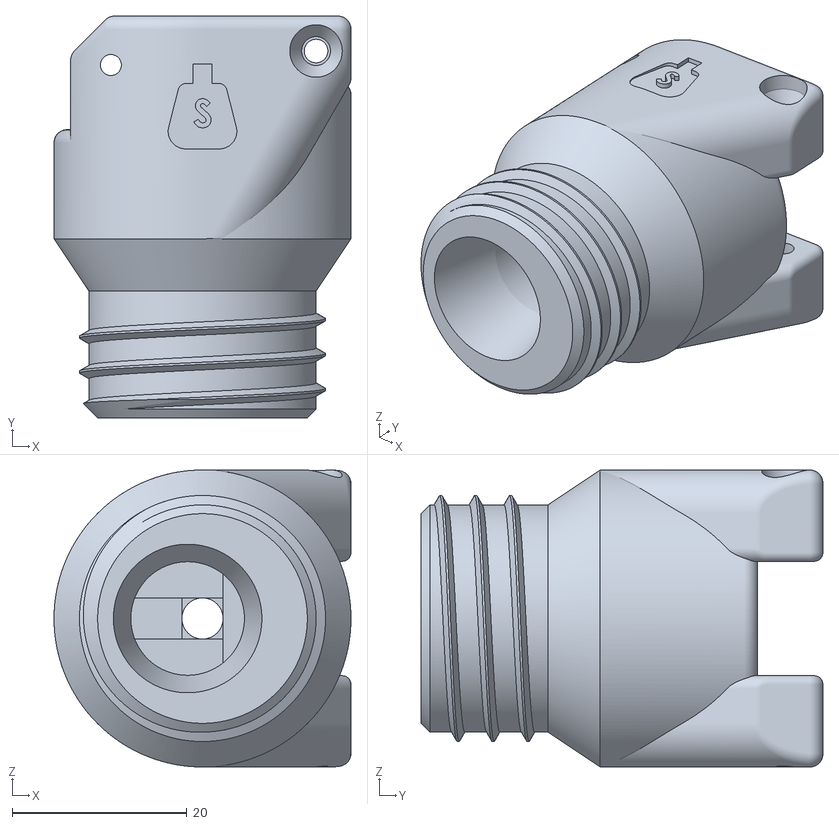
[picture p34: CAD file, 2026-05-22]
V5/STL/ImpactFuse/FuseV5.STL
34.0 x 46.0 x 34.0

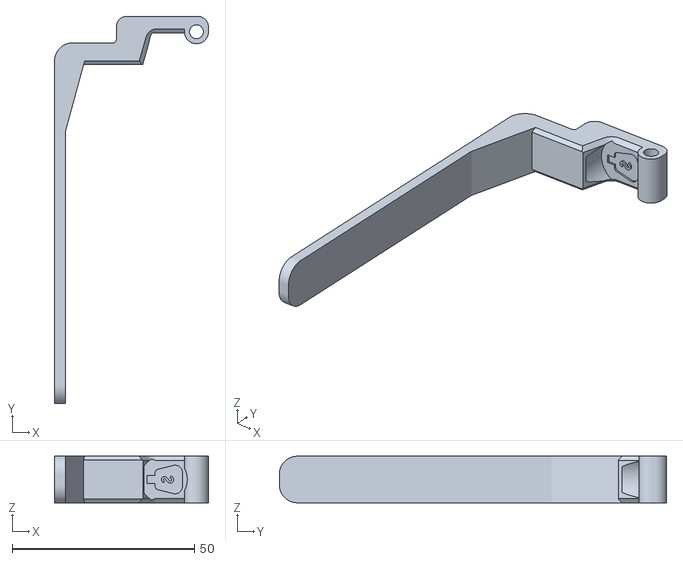
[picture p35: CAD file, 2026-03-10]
V5/STL/ImpactFuse/Spoon/Spoon38PrimerLongHexV5.STL
42.3 x 106.4 x 12.8

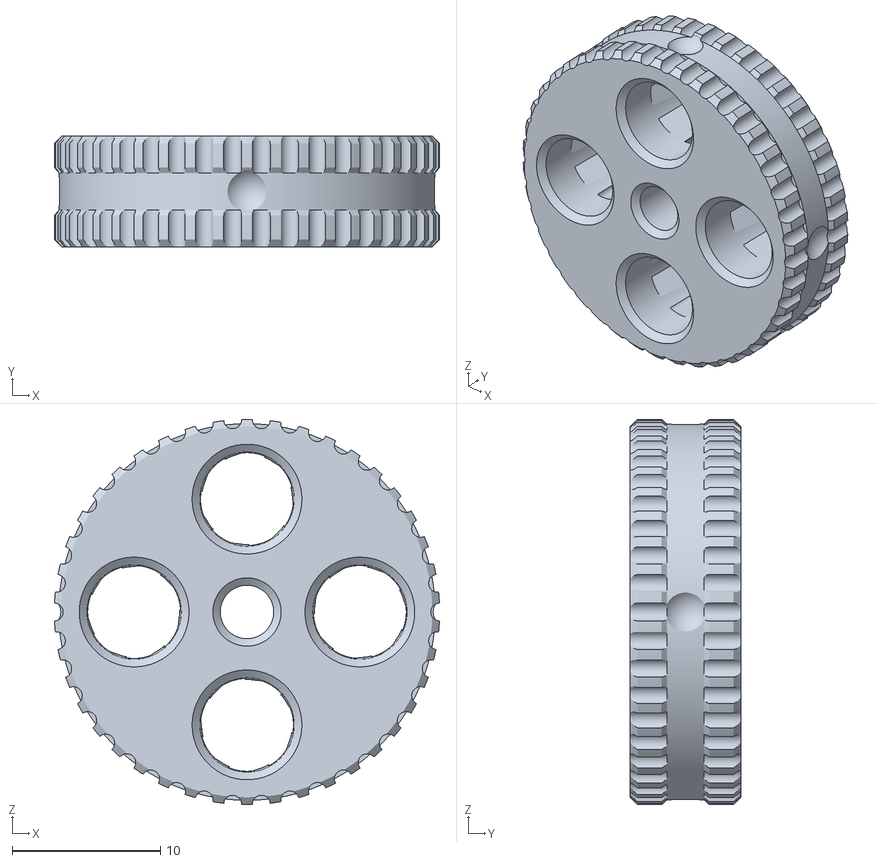
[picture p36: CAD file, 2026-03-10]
V5/STL/PrimerBody/Holder_X4.STL
26.0 x 7.50 x 26.0

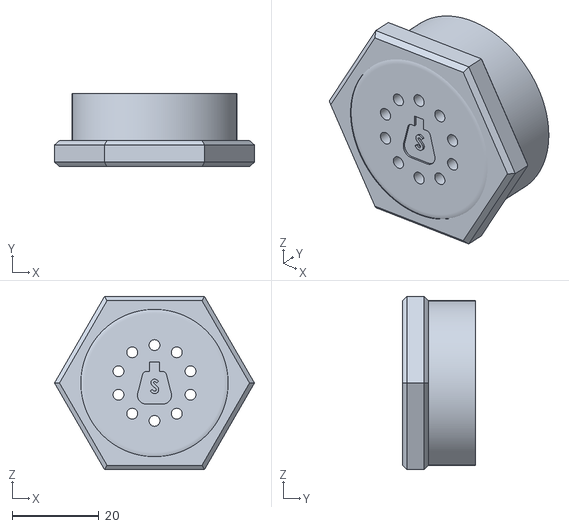
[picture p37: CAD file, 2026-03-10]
V5/STL/SnapBody/DS38V5BaseHex.STL
46.2 x 16.9 x 40.0

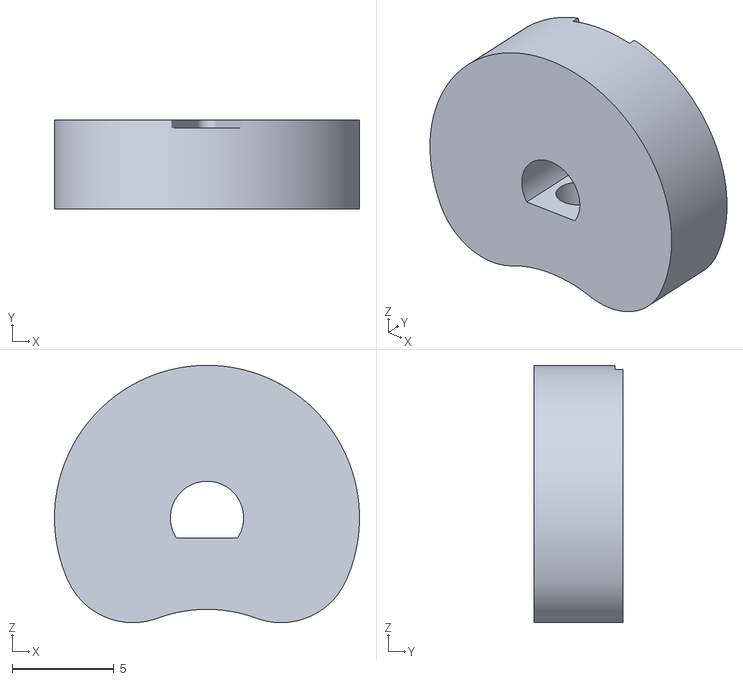
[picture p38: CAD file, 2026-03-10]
V5/STL/TimedFuse/CamV5.STL
15.0 x 4.40 x 12.7

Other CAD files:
Depricated/V4/8CapBodies/Retainer.STEP
Depricated/V4/ImpactFuse/Spoons/Spoon61P.STEP
Depricated/V4/ImpactFuse/V4Fuse.STEP
Depricated/V4/PrimerBodies/DS38PL.STEP
Depricated/V3/DS40/DS40Bottom.STEP
Depricated/V3/DS40/DS40BottomLong.STEP
Depricated/V3/DS40/DS40Top.STEP
Depricated/V3/DS40F/DS40FBottom.STEP
Depricated/V3/DS40F/DS40FBottomLong.STEP
Depricated/V3/DS40F/DS40FTop.STEP
Depricated/V3/DS40F/DS40FTop_NoText.STEP
Depricated/V3/DS67/DS67Bottom.STEP
Depricated/V3/DS67/DS67Top.STEP
Depricated/V3/Experimental/fuse.STEP
Depricated/V3/Experimental/fuseSmallSafety.STEP
Depricated/V3/Experimental/pla.STEP
Depricated/V3/Experimental/tpu.STEP
Depricated/V3/Fuse/Fuse M3x4x5 heatinsert.STEP
Depricated/V3/Fuse/Fuse.STEP
Depricated/V3/Fuse/FuseLatch.STEP
Depricated/V3/Fuse/SpringPlate.STEP
Depricated/V3/Fuse/SpringPlateNylonNut.STEP
Depricated/V3/Fuse/TPUSpoon Curved.STEP
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

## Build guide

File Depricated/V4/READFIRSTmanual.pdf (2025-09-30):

Last Updated May 2025

## Airsoft Sound Device V4

## PLEASE READ THE INSTRUCTIONS THOROUGHLY AND WATCH THE VIDEO LINKED BELOW BEFORE ASKING QUESTIONS

The timed fuse assembly is not detailed in this document but can be found in the video

Assembly video can be found here: https://youtu.be/RjEWMC33Hto

A video showing how to order the PCBs is located in the PCB files folder as well as the necessary files for the PCB

For further questions and resources join the discord server:

https://discord.gg/FcNPHcn7kz

These are strictly for training and airsoft purposes. I do not assume responsibility for your misuse.

## Table of Contents

File Outline | Page 3
Print Settings and Materials | Page 4
Impact Fuse Bill of Materials | Page 6
PCB Timer Fuse Bill of Materials | Page 7
1s Lipo Timer Fuse Bill of Materials | Page 8
Cr2032 Timer Fuse Bill of Materials | Page 9
Impact Fuse Assembly | Page 10
Grenade Body Function | Page 15

## File Outline

Files are organized into assigned folders and named with association to each other.

For the bodies. Files ending in P are primer bodies. Files ending with an 8 are 8 shot cap bodies. Files ending with an S are adult, thunder, super snap bodies.
For the 38 bodies an ending with F delineates the flash or hexagon version of the body

For the Impact Fuse you will need the fuse, spring plate, bolt guide, and corresponding spoon. The spoons are labeled in association with bodies size number and propellant. You can choose the heat insert version of the fuse for increased durability. The nylon nut spring plate also has increased durability.

For the Timed Fuse you will need the fuse, cam, spring plate, bolt guide, and corresponding cap. The recharge is for the lipo and the 2032 is for the button batteries. The nylon nut spring plate has increased durability.

## Print Settings and Materials

It is critical that your printer and filament are tuned correctly for good results. I recommend looking at this guide to ensure proper tuning. https://ellis3dp.com/Print-Tuning-Guide/

Print Settings:

0.2 - 0.3 mm layer height for the bodies and fuses

0.2mm layer height or less for the Timer Cam

Smaller layers may yield more accurate dimensions.

1.2mm Wall Thickness

2mm Top Layer

1.2mm Bottom Layer

15% Gyroid Infill (More is always recommended)

For the TPU spoons 2mm wall, top and bottom layers with 100% infill. The wall thickness is important for the layer orientation.

Material:

Use PLA+ For all components excluding the spoons

For the spoons use 95A TPU. It is critical that you use this variant of TPU. Other flexibilities will yield varying results. It is highly recommended that you use TPU spoons. They will yield drastically better performance and impact strength.

The bottoms of the snap bodies may be printed from TPU.

Nylon or any fiber reinforced variant will work as a replacement for PLA+. There has been no recorded physical benefit over pla+ other than temperature resistance.

PETG and fiber reinforced variants have yielded varying results.

ABS and ASA are not suitable because of their weaker layer adhesion.

Print Orientation:

For the fuse, print with the bottom on the build plate and with support for the hole in the bottom. The Timed fuse can be printed similarly with support also needed for the cam region. You may be able to get away without support for the hole in the bottom, but results will depend on your printers’ capabilities.

All grenade bodies will be printed with their bottoms on the build plate. Support is not needed. The 55S body is the only exclusion and will need to be inverted and requires support.

The spoons can be printed sideways without the need for support.

## Impact Fuse Bill of Materials

Please VERIFY that you are ordering the same size components listed below. The links do not direct you to the exact size/spec you will need.

Item | Quantity | Link | Notes:
M5x40mm SHCS Half Thread | 1 | X (https://www.aliexpress.us/item/3256802084429657.html?scm_id=1007.40050.354490.0&scm-url=1007.40050.354490.0) X (https://www.amazon.com/dp/B0DDKFXLC5?ref_=ppx_hzsearch_conn_dt_b_fed_asin_title_1)
M3x30mm SHCS | 1 | X (https://www.aliexpress.us/item/2251832624557792.html)
12mm od x 45mm 1.2mm diameter spring. 8 coils | 1 | X (https://www.aliexpress.us/item/2255800219014836.html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) X (https://www.amazon.com/dp/B076M2CBSX?ref_=ppx_hzsearch_conn_dt_b_fed_asin_title_2) | See Comments Below Chart
25mm keyring | 1 | X (https://www.aliexpress.us/item/3256804511691476.html)
M2.5x35mm Cotter Pin | 1 | X (https://www.aliexpress.us/item/3256804075588876.html)
M3 Brass Insert 5mmODx4mmL | 1 | X (https://www.aliexpress.us/item/3256803396040989.html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) | Not necessary, only for increased durability
M5 Lock Nut | 1 | X (https://www.aliexpress.us/item/2251832612458814.html) X (https://www.amazon.com/uxcell-Hex-Lock-Nuts-Self-Locking/dp/B07MNJJQJS?s=industrial)

Springs ordered from other locations may have differing coil counts. The recommended coil count is 8. In the case the spring is unable to compress enough, either cut and stretch the spring, or purchase a shorter length and stretch to fit. If you find your springs too weak, increase in length. The 40mm uxcell springs on amazon will need to be trimmed to work. I recommend purchasing a few varying lengths or further discuss with others on the discord to find a good spring.

I have noticed that springs will lose their strength over time and will need to be replaced. Avoid leaving the fuses cocked over long periods of time, this will rapidly decrease their lifespan.

## PCB TIMED Bill of Materials (Recommended)

Please VERIFY that you are ordering the same size components listed below. The links do not direct you to the exact size/spec you will need.

Item | Quantity | Link | Notes:
M5x40mm SHCS Half Thread | 1 | X (https://www.aliexpress.us/item/3256802084429657.html?scm_id=1007.40050.354490.0&scm-url=1007.40050.354490.0) X (https://www.amazon.com/dp/B0DDKFXLC5?ref_=ppx_hzsearch_conn_dt_b_fed_asin_title_1)
12mm od x 40mm 1.2mm diameter spring | 1 | X (https://www.aliexpress.us/item/2255800219014836.html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) X (https://www.amazon.com/dp/B076M2CBSX?ref_=ppx_hzsearch_conn_dt_b_fed_asin_title_2) | See comments below the Impact Fuse chart
M5 Lock Nut | 1 | X (https://www.aliexpress.us/item/2251832612458814.html) X (https://www.amazon.com/uxcell-Hex-Lock-Nuts-Self-Locking/dp/B07MNJJQJS?s=industrial) | Not necessary, only for increased durability
Motor 12V 30RPM | 1 | X (https://www.amazon.com/uxcell-Micro-Motor-10RPM-Reducer/dp/B01ES98QSG) X (https://www.amazon.com/DC-Motor-1000-Miniature-3V-12V/dp/B08K9B1W5M/ref=sr_1_2?s=industrial&sr=1-2) | It is Very important that you purchase a 12V 30rpm motor. The gearbox is 12.5mm vs the standard 9mm. The gearbox has a 1:1000 ratio. Please be careful to order the correct motor others will not work
100mAh 3.7v LiPo with jst GH 1.25mm connector | 2 | X (https://www.aliexpress.us/item/3256805134882095.html) X (https://www.amazon.com/100mAh-Battery-WLtoys-Cheerson-Quadcopter/dp/B08FWZBYC2/ref=sr_1_6?sr=8-6) | Reminder you will need two per fuse
Male-to-Male jst XH 2.5mm 3pin connector | 1 | | You can either crimp a custom connector or solder two male 2s balance leads together. This will be used to charge the fuse with a standard 2s lipo charger
M2x10mm self-tapping screw | 3 | X (https://www.aliexpress.us/item/3256805283174663.html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) X (https://www.amazon.com/uxcell-100pcs-Stainless-Phillips-Tapping/dp/B01KXTUCM8?sp_csd=d2lkZ2V0TmFtZT1zcF9hdGY)
M2.5x3mm Set Screw | 1 | X (https://www.aliexpress.us/item/2255800895118752.html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) X (https://www.amazon.com/100pcs-Stainless-Socket-Screws-Metric/dp/B01MTM26H0/ref=sr_1_9?sr=8-9)
PCB | 1 | | PCB files are included in the files. A video showing how to order is linked above.
JST GH 1.25mm 2pin Female | 2 | X (https://www.amazon.com/dp/B0B3NGZG5N) | For the batteries
JST XH 2.5mm 3pin Female | 1 | X (https://www.amazon.com/CQRobot-Connector-Terminals-Housing-Adapter/dp/B0B2R99X99?s=industrial) | Charge connector
Switch | 1 | X (https://www.digikey.com/en/products/detail/c-k/OS102011MS2QN1/411602)

## 1s LiPo TIMED Bill of Materials

Please VERIFY that you are ordering the same size components listed below. The links do not direct you to the exact size/spec you will need.

Item | Quantity | Link | Notes:
M5x40mm SHCS Half Thread | 1 | X (https://www.aliexpress.us/item/3256802084429657.html?scm_id=1007.40050.354490.0&scm-url=1007.40050.354490.0) X (https://www.amazon.com/dp/B0DDKFXLC5?ref_=ppx_hzsearch_conn_dt_b_fed_asin_title_1)
12mm od x 45mm 1.2mm diameter spring. 8 coils | 1 | X (https://www.aliexpress.us/item/2255800219014836.html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) X (https://www.amazon.com/dp/B076M2CBSX?ref_=ppx_hzsearch_conn_dt_b_fed_asin_title_2) | See comments below the Impact Fuse chart
M5x0.8mm Lock Nut | 1 | X (https://www.aliexpress.us/item/2251832612458814.html) X (https://www.amazon.com/uxcell-Hex-Lock-Nuts-Self-Locking/dp/B07MNJJQJS?s=industrial) | Not necessary, only for increased durability
Motor 12V 30RPM | 1 | X (https://www.amazon.com/uxcell-Micro-Motor-10RPM-Reducer/dp/B01ES98QSG) X (https://www.amazon.com/DC-Motor-1000-Miniature-3V-12V/dp/B08K9B1W5M/ref=sr_1_2?s=industrial&sr=1-2) | It is Very important that you purchase a 12V 30rpm motor. The gearbox is 12.5mm vs the standard 9mm. The gearbox has a 1:1000 ratio. Please be careful to order the correct motor others will not work
160mAh 3.7v LiPo | 1 | X (https://www.aliexpress.us/item/3256803607900821.html) | It is possible to fit a 260mAh battery, however it will be a tight fit
Battery Charger | 1 | X (https://www.aliexpress.us/item/3256805188287193.html) | Any other 1s charger will work, you will just need to add a male JST connector to it
Connectors JST SYP 2.5mm 2pin | 2 | X (https://www.aliexpress.us/item/2251832685834187.html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) X (https://www.amazon.com/CQRobot-Connector-Industrial-Integrated-Electronics/dp/B07QKMBLWR?s=industrial) | I strongly recommend against buying pre crimped connectors and soldering too them. It will take a large amount of space
Crimper JST | 1 | X (https://www.aliexpress.us/item/3256807371774039.html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) X (https://www.amazon.com/Knoweasy-Crimper-Compatible-Dupont-terminals/dp/B0DNLYJTHC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)
On/Off Switch | 1 | X (https://www.aliexpress.us/item/2251832626374457.html)
M2x10mm self-tapping screw | 3 | X (https://www.aliexpress.us/item/3256805283174663.html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) X (https://www.amazon.com/uxcell-100pcs-Stainless-Phillips-Tapping/dp/B01KXTUCM8?sp_csd=d2lkZ2V0TmFtZT1zcF9hdGY)
M2.5x3mm Set Screw | 1 | X (https://www.aliexpress.us/item/2255800895118752.html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) X (https://www.amazon.com/100pcs-Stainless-Socket-Screws-Metric/dp/B01MTM26H0/ref=sr_1_9?sr=8-9)
Wire | | | Any 26-28awg wire
Hot Glue | | | For securing the solder connections

## Cr2032 TIMED Bill of Materials

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

Item | Quantity | Link | Notes:
M5x40mm SHCS Half Thread | 1 | X (https://www.aliexpress.us/item/3256802084429657.html?scm_id=1007.40050.354490.0&scm-url=1007.40050.354490.0) X (https://www.amazon.com/dp/B0DDKFXLC5?ref_=ppx_hzsearch_conn_dt_b_fed_asin_title_1)
12mm od x 40mm 1.2mm diameter spring | 1 | X (https://www.aliexpress.us/item/2255800219014836.html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) X (https://www.amazon.com/dp/B076M2CBSX?ref_=ppx_hzsearch_conn_dt_b_fed_asin_title_2) | See comments below the Impact Fuse chart
M5 Lock Nut | 1 | X (https://www.aliexpress.us/item/2251832612458814.html) X (https://www.amazon.com/uxcell-Hex-Lock-Nuts-Self-Locking/dp/B07MNJJQJS?s=industrial) | Not necessary, only for increased durability
Motor 12V 30RPM | 1 | X (https://www.amazon.com/uxcell-Micro-Motor-10RPM-Reducer/dp/B01ES98QSG) X (https://www.amazon.com/DC-Motor-1000-Miniature-3V-12V/dp/B08K9B1W5M/ref=sr_1_2?s=industrial&sr=1-2) | It is Very important that you purchase a 12V 30rpm motor. The gearbox is 12.5mm vs the standard 9mm. The gearbox has a 1:1000 ratio. Please be careful to order the correct motor others will not work
CR2032 Battery Holder | 2 | X (https://www.aliexpress.us/item/3256804946160490.html) X (https://www.amazon.com/Alinan-Button-Battery-Storage-Container/dp/B09KTVG1Y5/ref=sr_1_3?sr=8-3)
M2x10mm self-tapping screw | 3 | X (https://www.aliexpress.us/item/3256805283174663.html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) X (https://www.amazon.com/uxcell-100pcs-Stainless-Phillips-Tapping/dp/B01KXTUCM8?sp_csd=d2lkZ2V0TmFtZT1zcF9hdGY)
M2.5x3mm Set Screw | 1 | X (https://www.aliexpress.us/item/2255800895118752.html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) X (https://www.amazon.com/100pcs-Stainless-Socket-Screws-Metric/dp/B01MTM26H0/ref=sr_1_9?sr=8-9)
Hot Glue | | | For securing the solder connections

## Impact Fuse Assembly

1. To start for the primer version only, grind the end of the fuse screw (m5x40mm) to a bevel as shown in the image below. This applies for the timed fuse as well.

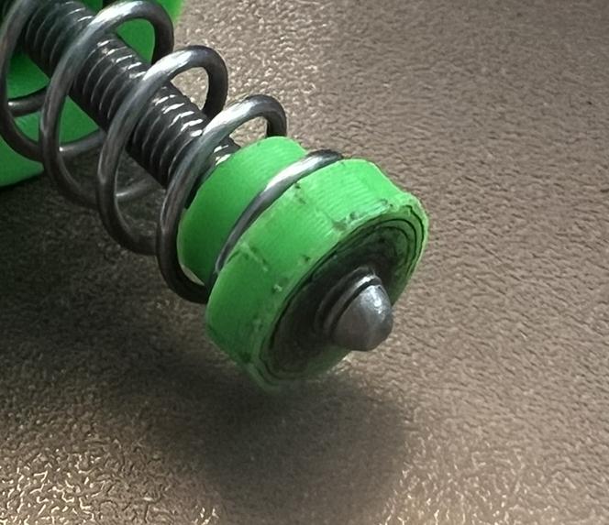
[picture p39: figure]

2. Press the bolt guide onto the M5x40mm bolt. This will likely take some force. A tool is included to help press the guide on. It is recommended to also use glue to ensure that it will not separate under prolonged use. It may be necessary to sand the guide to fit the hole in the fuse. Verify that the guide is also sitting relatively straight on the bolt. The fitment of the guide and bolt in the fuse is not critical to the reliability of the grenade like V3, however it will perform best with a good fitment. This applies for the timed fuse as well.

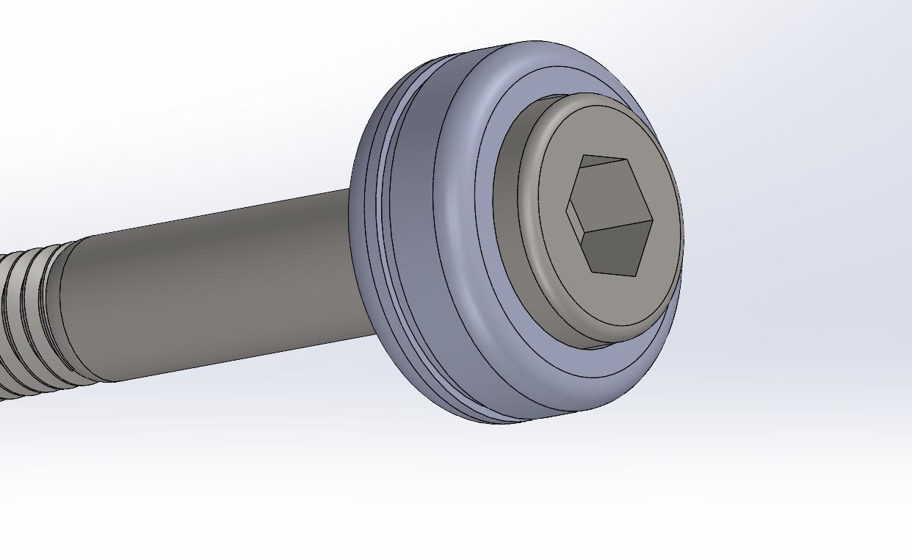
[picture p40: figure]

3. Secure the screw and spring in the fuse with the spring retainer. For use with primers ensure that the bolt sticks out ~2mm past the spring retainer as seen in the photo below. This applies for the timed fuse as well.

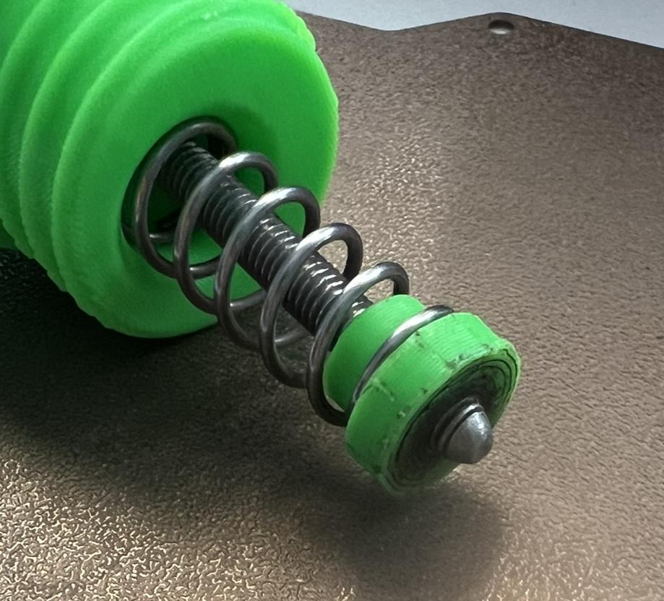
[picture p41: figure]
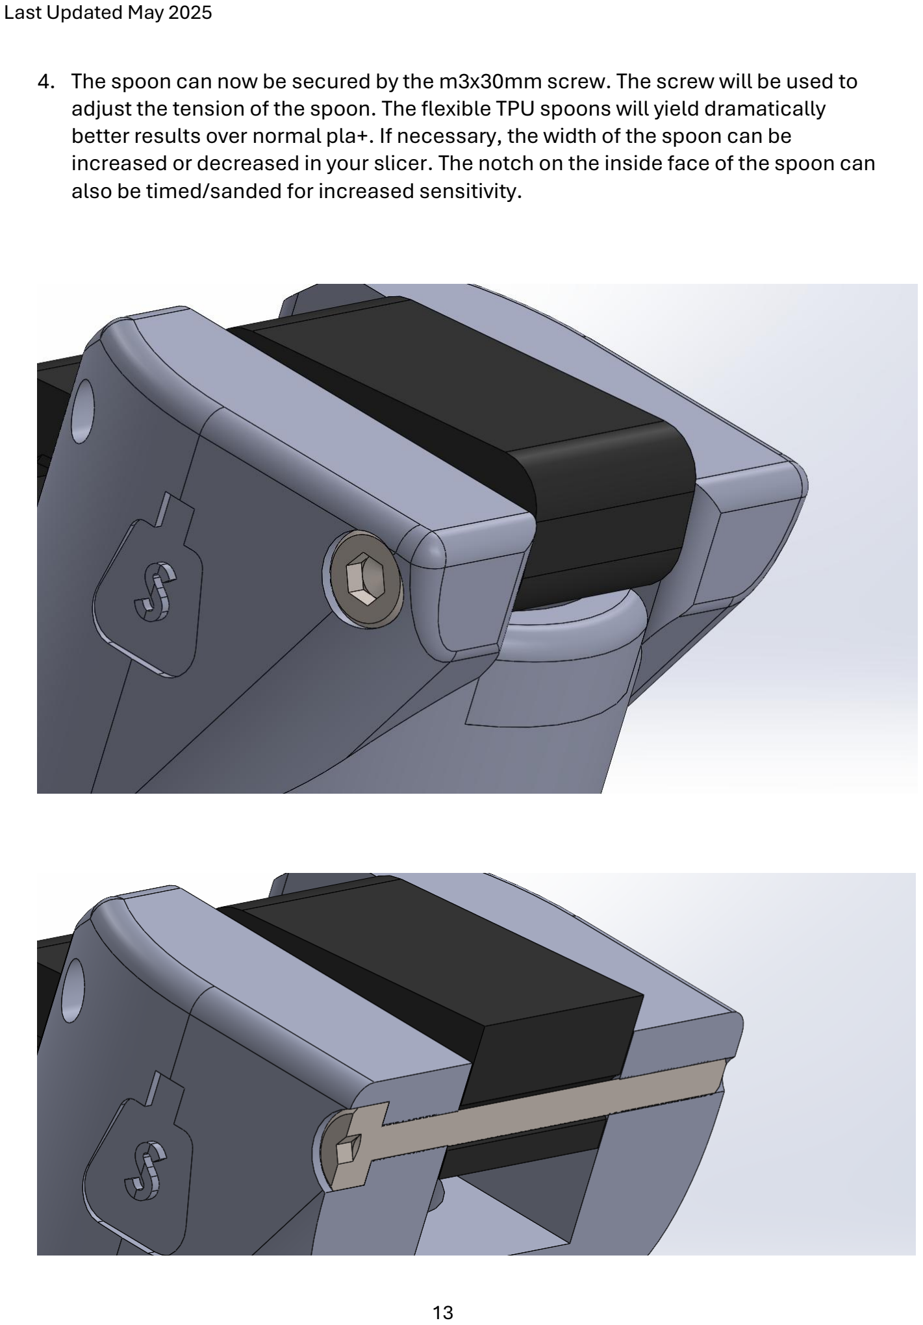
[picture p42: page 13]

4. The spoon can now be secured by the m3x30mm screw. The screw will be used to adjust the tension of the spoon. The flexible TPU spoons will yield dramatically better results over normal pla+. If necessary, the width of the spoon can be increased or decreased in your slicer. The notch on the inside face of the spoon can also be timed/sanded for increased sensitivity.

5. In order to prime the fuse, the m5 screw needs to be pushed up and towards the rear as shown in the image below. The spoon will then be lowered in order to hold the screw from dropping. As stated before, you can tighten or loosen the spoon screw to adjust the tension.

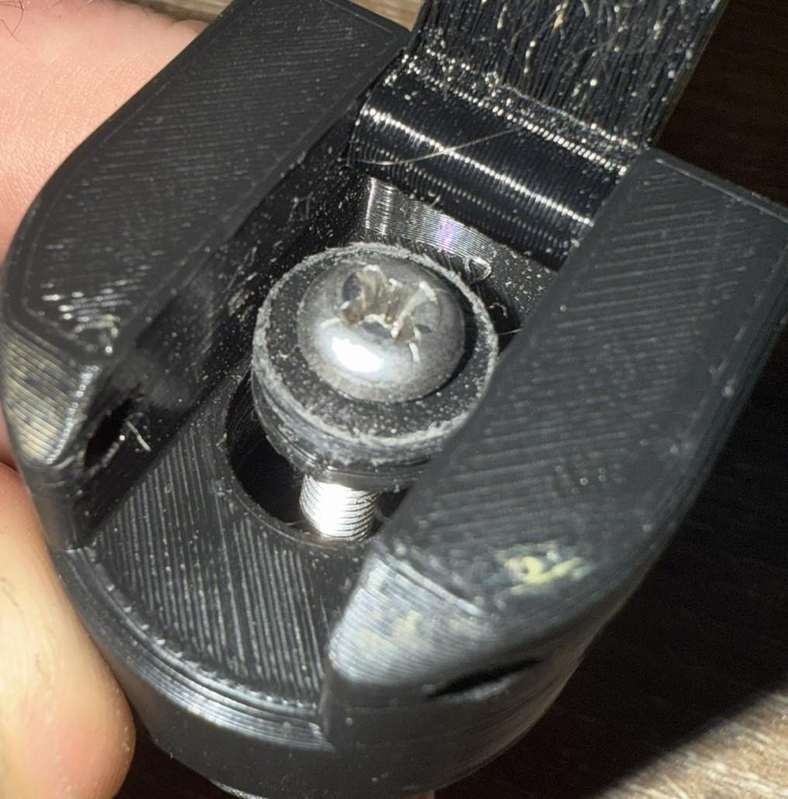
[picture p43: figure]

The screw is not supposed to latch on the top and should free fall unless something is blocking it. There is no spring on the spoon, that is counter intuitive to the design. The spoon is blocking the screw from falling into the hole. The fuse will trigger when the spoon moves away from the latch. This can be accomplished via a hard impact or simply moving the spoon. Again adjusting the friction on the spoon via the screw adjusts the force required for the spoon to move out of the way.

## Grenade Body Function

For all Bodies it may initially be difficult to thread the fuse onto the bodies. This is due to the way the threads are printed. Thread a small amount at a time and go back and forth to work them in.

For the Primer Bodies. The Primer will be loaded in the location outlined in the photo below. It can be pushed out after use from the bottom of the body. If the hole is not the right size I suggest adjusting your flow rate for scaling the body.

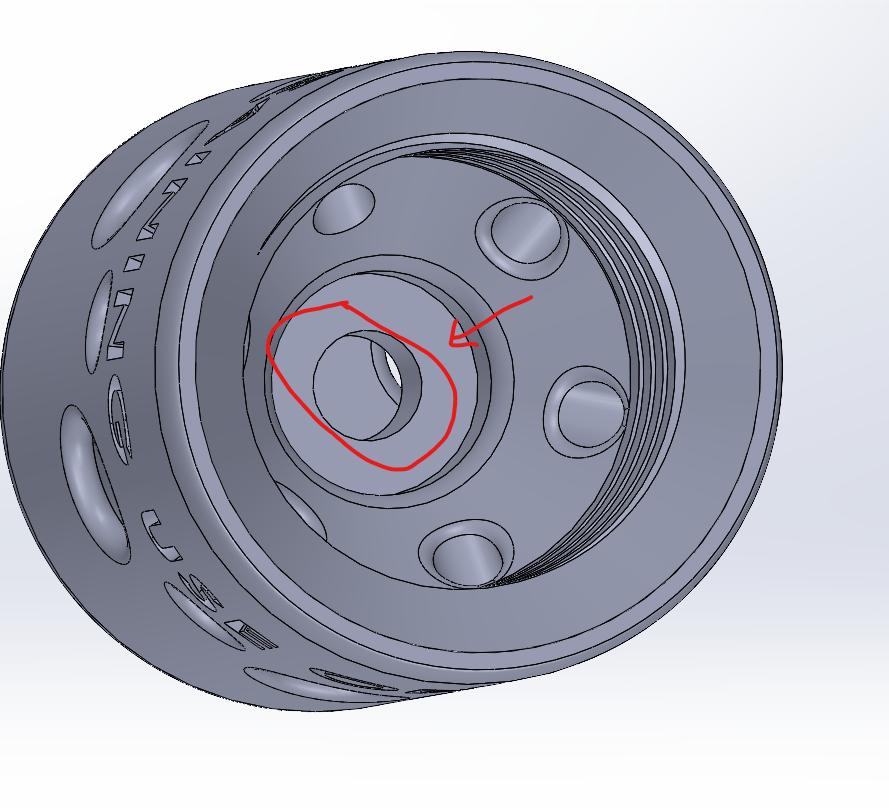
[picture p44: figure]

For the 8 shot cap bodies, the 8 shot cap can then be placed over the retainer then placed in the body as seen below.

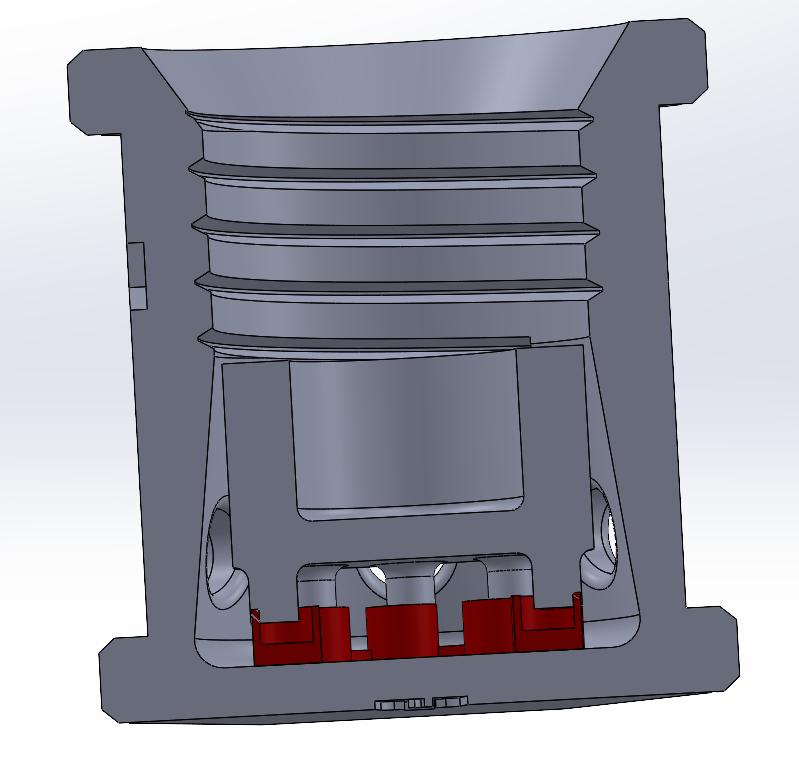
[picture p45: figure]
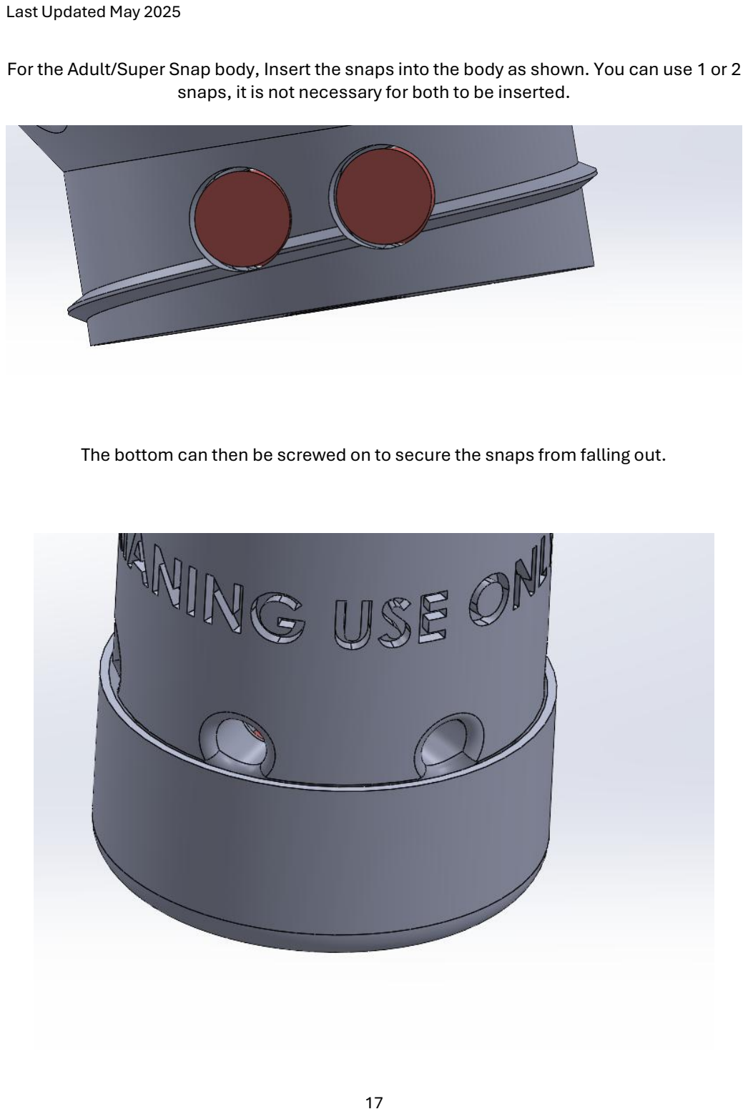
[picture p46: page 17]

For the Adult/Super Snap body, Insert the snaps into the body as shown. You can use 1 or 2 snaps, it is not necessary for both to be inserted.

The bottom can then be screwed on to secure the snaps from falling out.

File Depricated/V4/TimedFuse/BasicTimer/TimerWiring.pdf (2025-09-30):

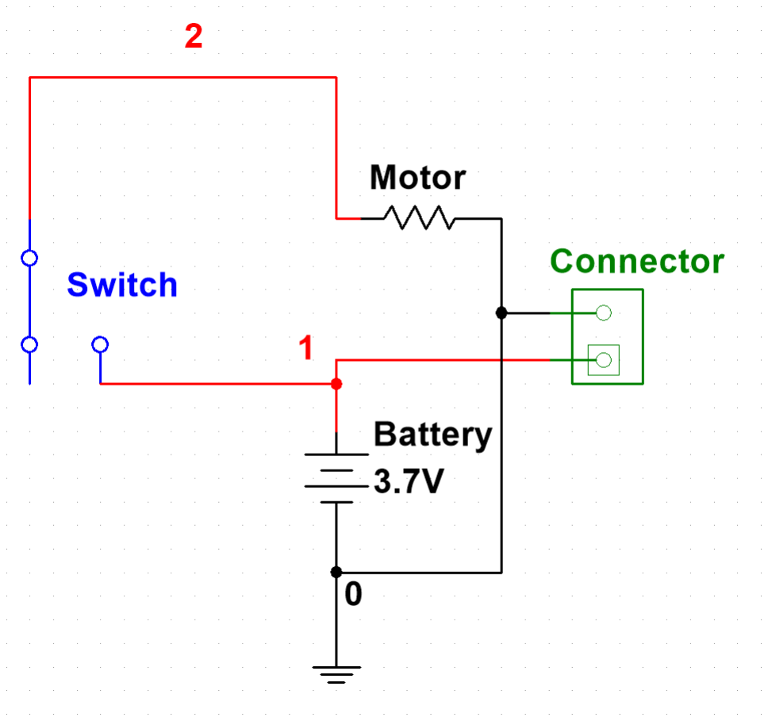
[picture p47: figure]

Figure 1 Rechargeable

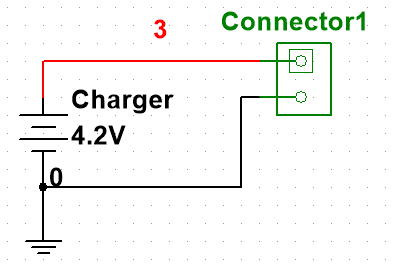
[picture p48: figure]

Figure 2 Charger

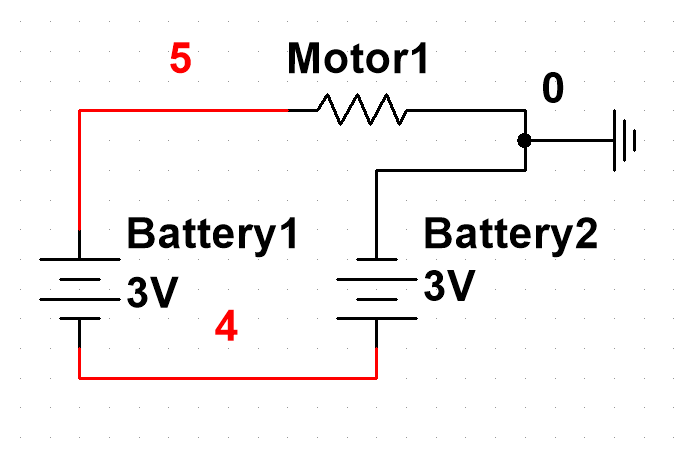
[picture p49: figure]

Figure 3 CR232 Batteries

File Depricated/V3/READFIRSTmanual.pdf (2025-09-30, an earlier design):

Last Updated February 2025

## Airsoft Sound Device V3

## PLEASE READ THE INSTRUCTIONS THOROUGHLY AND WATCH THE VIDEO LINKED BELOW BEFORE ASKING QUESTIONS

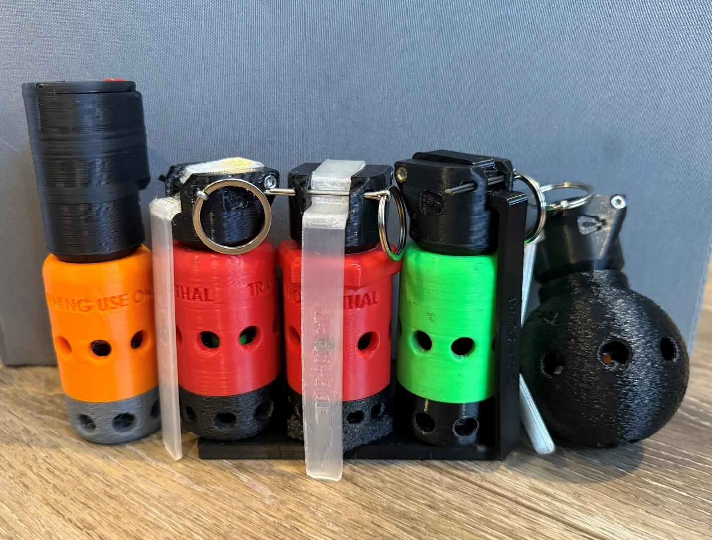
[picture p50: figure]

The timed fuse assembly is not detailed in this document but can be found in the video.

Assembly video can be found here: https://youtu.be/n1GOHsLrYXg

The hardware BOM for both fuse types are on the following pages

IMPACT Bill of Materials

Please verify that you are ordering the same size components listed below. The links do not direct you to the exact size/spec you will need.

Item | Quantity | Link | Notes:
M5x50mm | 1 | X (https://www.aliexpress.us/item/3256803061463013.html)
M3x30mm SHCS | 1 | X (https://www.aliexpress.us/item/2251832624557792.html)
12mm od x 40mm 1.2mm diameter spring | 1 | X (https://www.aliexpress.us/item/3256801468818282.html) | Spring sizes from 40-50mm in length will all work
25mm keyring | 1 | X (https://www.aliexpress.us/item/3256804511691476.html)
M2.5x35mm Cotter Pin | 1 | X (https://www.aliexpress.us/item/3256804075588876.html)
M3 Brass Insert 5mmODx4mmL | 1 | X (https://www.aliexpress.us/item/3256803396040989.html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) | Not necessary, only for increased durability
M5 Lock Nut | 1 | X (https://www.aliexpress.us/item/2251832612458814.html)

TIMED Bill of Materials

Please verify that you are ordering the same size components listed below. The links do not direct you to the exact size/spec you will need.

For the rechargeable design you do not need the CR2032 Battery holders. For the CR2032 design you do not need the liPo, charger, connectors, or switch.

Item | Quantity | Link | Notes:
M5x50mm | 1 | X (https://www.aliexpress.us/item/3256803061463013.html)
12mm od x 40mm 1.2mm diameter spring | 1 | X (https://www.aliexpress.us/item/3256801468818282.html) | A length of 40mm is recommended. Longer springs will increase the force upon the motor
M5 Lock Nut | 1 | X (https://www.aliexpress.us/item/2251832612458814.html) | Not necessary, only for increased durability
Motor 12V 30RPM | 1 | X (https://www.aliexpress.us/item/3256805054632364.html) | It is Very important that you purchase a 12V 30rpm motor. Others will not be strong enough. 6v 15rpm and 3v 7.5rpm motors are not equivalent substitutions.
CR2032 Battery Holder | 2 | X (https://www.aliexpress.us/item/3256804946160490.html)
160mAh 3.7v LiPo | 1 | X (https://www.aliexpress.us/item/3256803607900821.html) | It is possible to fit a 260mAh, however it will be a very tight fit
Battery Charger | 1 | X (https://www.aliexpress.us/item/3256805188287193.html) | Any other 1s charger will work, you will just need to add a male JST connector to it
Connectors JST | 2 | X (https://www.aliexpress.us/item/2251832685834187.html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) | I strongly recommend against buying pre crimped connectors and soldering too them. It will take a large amount of space
Crimper JST | 1 | X (https://www.aliexpress.us/item/3256807371774039.html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)
On/Off Switch | 1 | X (https://www.aliexpress.us/item/2251832626374457.html)
M2x10mm self-tapping screw | 3 | X (https://www.aliexpress.us/item/3256805283174663.html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)
M2.5x3mm Set Screw | 1 | X (https://www.aliexpress.us/item/2255800895118752.html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)
Wire | | | Any 26-28awg wire
Hot Glue | | | For securing the solder connections

1. Print all parts in pla+ except the spoon must be printed in TPU 95A. IT IS HIGHLY RECOMMENDED THAT YOU USE TPU SPOONS. Do not print any other components in TPU, it will cause issues. Minimum of 1.2mm walls, 2mm top layer, 1.2mm bottom layer, and 15% infill. At maximum 0.3mm layer height. It is recommended that you use support for the screw hole on the fuse. The timed design will need support in the cam cavity. The DS67 bottom can be printed vertically opposite of what is shown in the photo below without support. However, if your printer struggles to bridge you can also print it as shown in the picture below with support. Make sure you do not have supports on the inside they will be impossible to remove. The smaller RP body must be printed upside down, as shown below, with support. Like the 67 make sure there are no supports in the bottom chamber you will not be able to remove them. The RP body is a very difficult print.

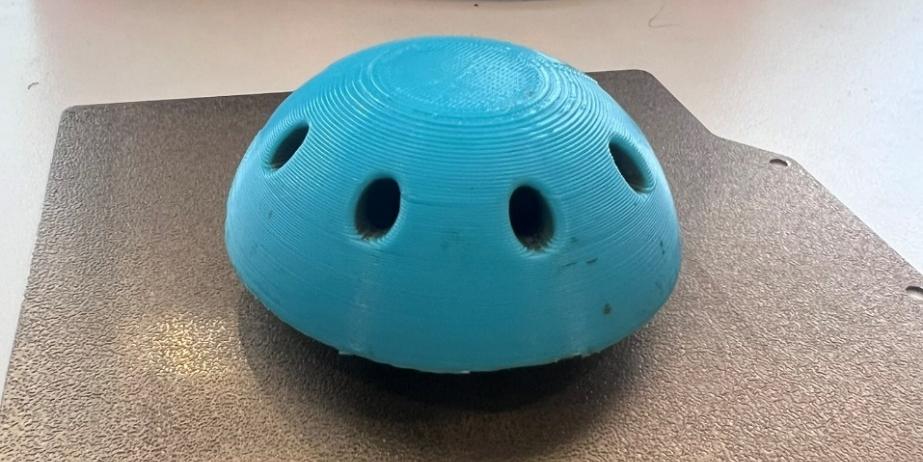
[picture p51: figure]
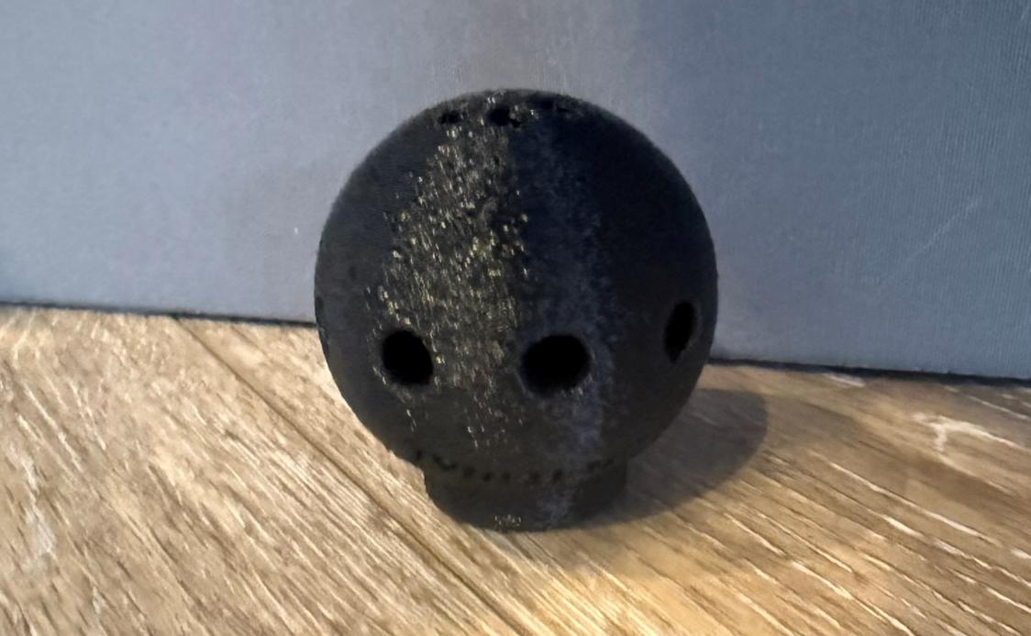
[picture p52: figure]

2. Grind the end of the fuse screw (m5x50mm) to a bevel as shown in the image below. The screw needs to stick out ~2mm like the image shows. Do not make it into a point, it needs to be large and rounded.


3. Screw the latch guide onto the m5 screw. One side has a beveled end that must face away from the screw head. It may be necessary to sand the latch to fit the hole. It is important that the latch is not too loose or tight, but as close to a perfect fit as possible. I will discuss this further in the included video. If necessary, the diameter of the latch can be increased or decreased in your slicer.

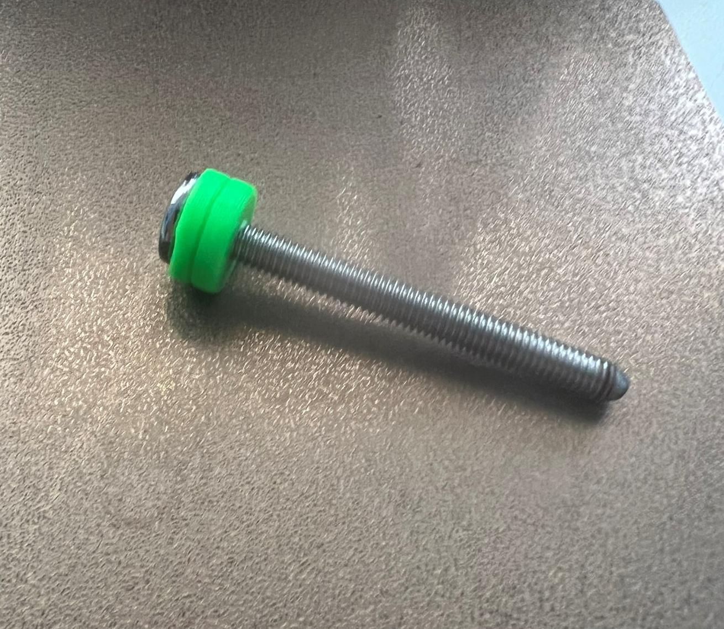
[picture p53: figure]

4. Secure the screw and spring in the fuse with the spring retainer.


5. The flexible spoons will yield dramatically better results over normal pla+. The spoon can be secured by the m3x30mm screw. The screw will be used to adjust the tension of the spoon. In order to prime the fuse, the m5 screw needs to be pushed up and towards the rear as shown in the image below. The spoon will then be lowered in order to hold the screw from dropping. As stated before, you can tighten or loosen the spoon screw to adjust the tension. If necessary, the width of the spoon can be increased or decreased in your slicer.


The screw is not supposed to latch on the top and should free fall unless something is blocking it. There is no spring on the spoon, that is counter intuitive to the design. The spoon is blocking the screw from falling into the hole. The fuse will trigger when the spoon moves away from the latch. This can be accomplished via a hard impact or simply moving the spoon.

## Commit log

2026-01-04 Add README for Airsoft Sound Device V4.5
2026-01-04 new file: V4.5/images/8cap_body.png new file: V4.5/images/add_screw.JPEG new file: V4.5/images/battery_install.png new file: V4.5/images/battery_side.png new file: V4.5/images/battery_top.png new fil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
2026-01-04 Update README with slicer settings and material recommendations
    Added recommendations for layer height, infill, and material usage for better print quality.
2026-01-04 Update emphasis on material usage in README
2026-01-04 Correct emphasis on material usage guidelines
2026-01-04 Refine README with print orientation and remove duplicates
    Removed duplicate lines and added print orientation details.
2026-01-04 renamed: V4.5/images/8cap_body.png -> V4.5/Images/8cap_body.png renamed: V4.5/images/add_screw.JPEG -> V4.5/Images/add_screw.JPEG renamed: V4.5/images/battery_install.png -> V4.5/Images/battery_insta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
2026-01-04 new file: V4.5/ImpactFuse/BoltGuide.STL new file: V4.5/ImpactFuse/fuseV4.5.STL new file: V4.5/ImpactFuse/springplateV4.5.STL
    [BoltGuide.STL, fuseV4.5.STL, springplateV4.5.STL]
2026-01-04 Fix links and add printed parts for various fuses
2026-01-04 Include battery compartment images in README
    Added images for battery compartment dimensions.
2026-01-04 Update verification note in README for BOM sections
2026-01-04 Update README with detailed assembly instructions
    Expanded instructions for battery installation, cam assembly, and fuse charging process. Added images for clarity.
2026-01-04 Update README with material recommendations and settings
    Added guidelines for material selection and printing settings.
2026-01-04 Update material guidelines in README.md
    Clarified material recommendations and removed redundant information about TPU and other materials.
2026-01-04 modified: V4.5/README.md new file: V4.5/tool.STL
    [tool.STL]
2026-01-04 renamed: V3/DS40/DS40Bottom.STEP -> Depricated/V3/DS40/DS40Bottom.STEP renamed: V3/DS40/DS40BottomLong.STEP -> Depricated/V3/DS40/DS40BottomLong.STEP renamed: V3/DS40/DS40Top.STEP -> Depricated/V3/DS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
    [Cam.STEP, DS388.STEP, DS388F.STEP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]
2026-01-04 Update link to current release in readme.md
2026-01-04 Update link in deprecated readme for current release
2026-01-04 Update link in V3 readme to current release
2026-01-04 Revise README for clarity and detail on design
    Updated project description to enhance clarity and detail, including safety features and modular design aspects. Revised the note on inconsistencies with YouTube videos and added a current release li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
2026-01-08 new file: V4.5/PCB/PCBV2.0.0.zip new file: V4.5/PCB/bom.csv new file: V4.5/PCB/designators.csv new file: V4.5/PCB/positions.csv new file: V4.5/PCB/readme.md
    [bom.csv, designators.csv, positions.csv]
2026-03-10 modified: README.md deleted: V4.5/ImpactFuse/BoltGuide.STL deleted: V4.5/ImpactFuse/fuseV4.5.STL deleted: V4.5/ImpactFuse/springplateV4.5.STL deleted: V4.5/tool.STL renamed: V4.5/Images/8cap_body.png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
    [BoltGuide.STL, bom.csv, designators.csv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]
2026-03-10 new file: V5/STL/PrimerBody/DS38V5Body.STL new file: V5/STL/PrimerBody/DS38V5BodyHex.STL new file: V5/STL/PrimerBody/DS38V5BodyLong.STL new file: V5/STL/PrimerBody/DS38V5BodyLongHex.STL new file: V5/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
    [Holder_X4.STL, TestHole.STL]
2026-03-10 new file: V5/STL/CapBody/CapRetainerV5.STL new file: V5/STL/CapBody/DS38V5CapBody.STL new file: V5/STL/CapBody/DS38V5CapBodyHex.STL new file: V5/STL/CapBody/DS55V5CapBody.STL new file: V5/STL/ImpactF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
    [BoltGuideV5.STL, CamV5.STL, CapRetainerV5.STL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]
2026-03-10 new file: V5/Images/Holder.JPEG new file: V5/Images/HolderScrew.JPEG new file: V5/Images/PCBinsert.JPEG new file: V5/Images/bearing.JPEG deleted: V5/Images/bolt.JPEG new file: V5/Images/boltandguide.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

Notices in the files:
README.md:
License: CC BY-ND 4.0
